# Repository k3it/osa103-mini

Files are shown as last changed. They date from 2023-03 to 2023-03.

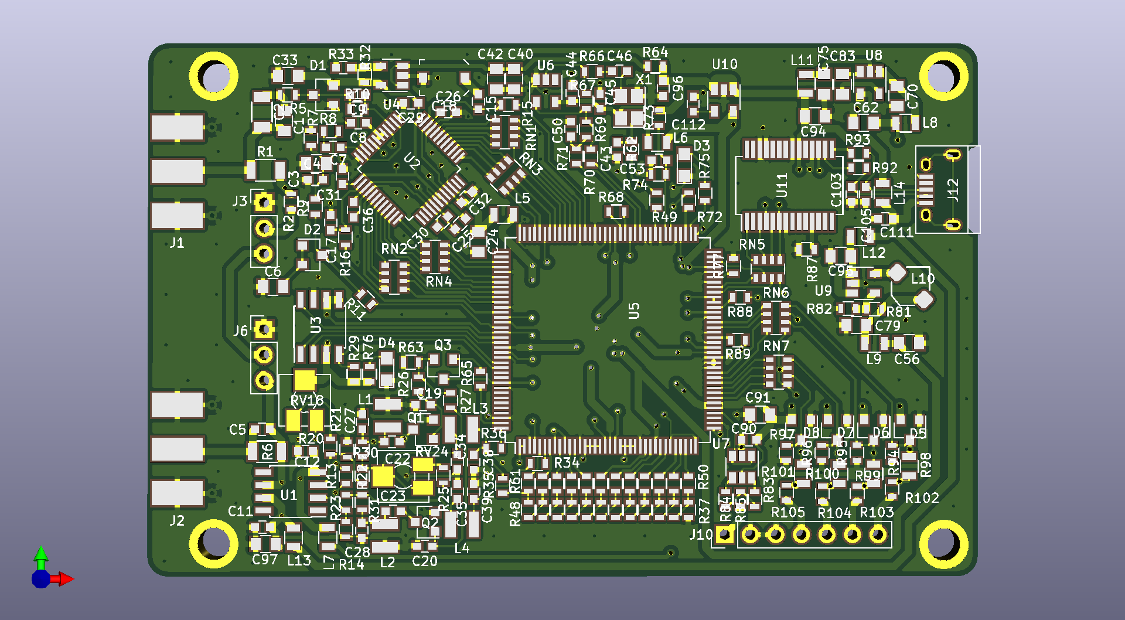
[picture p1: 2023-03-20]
osa103-mini/osa103k-pcb-front.png

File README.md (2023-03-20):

# osa103-mini
Software Defined Multifunctional Measurment Device - VNA, Oscilloscope, Antenna Analyzer, Signal Generator, SDR trasceiver etc

- Some years ago, I entered the OSA103 schematic, published by the device's author, into KiCad, and routed and created the PCB. I was able to assemble the device and was in the process of debugging it. It was a personal project undertaken out of pure curiosity and to learn KiCad. Unfortunately, my vision started to deteriorate to the point where troubleshooting a small SMD board was no longer enjoyable, and I ultimately abandoned the project. I am releasing all of the files from the project directory, including the gerbers, in case someone finds them useful.

- All credit for the original device goes to the person named Sergey from Perm, Russia. You may be able to reach him via a forum on a site called cqham or https://www.osa103.ru (which seems to be down as of spring 2023).   I have no contacts with the forum since the start of the war in Feb 2022.  

- Please note that you may need to pay for a software license to use the official software for this board. I haven't kept up with the development, so use this project at your own risk. That being said, this is an ingenious and clever device, so have fun!

- I have no affiliation or contact with the author or the websites mentioned above, and I have no idea about the author's position regarding the ongoing invasion of Ukraine. However, I hope that the author stands against it, which seems to be the case with the majority of intelligent people. When you communicate with Sergey may be  you will be able clarify his stance.  Thank you




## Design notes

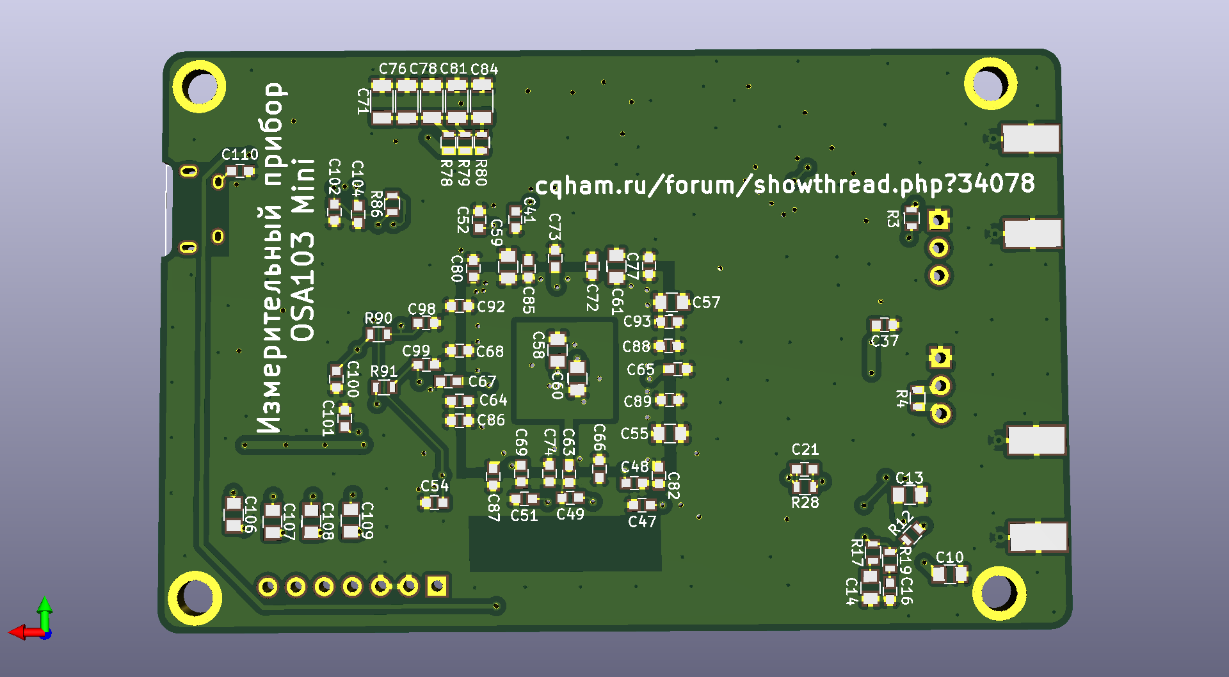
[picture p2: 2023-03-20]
osa103-mini/osa103k-pcb-back.png

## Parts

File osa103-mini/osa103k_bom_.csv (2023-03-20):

Component | Description | Part | References | Value | Footprint | Quantity Per PCB | Datasheet
1 | Unpolarized capacitor | C | C11 C12 C25 C26 C29 C31 C36 C46 C47 C48 C49 C50 C51 C53 C102 | 0.1uF | C_0603 | 15
2 | Unpolarized capacitor | C | C112 R33 | 10nF | C_0603 | 2
3 | Unpolarized capacitor | C | C1 C6 C10 C13 C24 C33 C40 C42 C55 C56 C57 C58 C59 C60 C61 C62 C70 C75 C79 C83 C91 C94 C95 C97 | 10uF | C_0805 | 24
4 | Unpolarized capacitor | C | C3 C15 C34 C35 | 15p | C_0603 | 4
5 | Unpolarized capacitor | C | C7 C8 C19 C20 C21 C22 C23 C30 C32 C37 C41 C43 C44 C45 C52 C63 C64 C65 C66 C67 C68 C69 C72 C73 C74 C77 C80 C82 C85 C86 C87 C88 C89 C90 C92 C93 C96 C98 C99 C100 C101 C104 C110 C111 | 1uF | C_0603 | 44
6 | Unpolarized capacitor | C | C5 C38 C39 | 2.2p | C_0603 | 3
7 | Unpolarized capacitor | C | C2 C71 C76 C78 C81 C84 | 22uF | C_1206 | 6
8 | Variable capacitor | C_Variable | C18 | 3..10p | C_Trimmer_Murata_TZC3 | 1
9 | Unpolarized capacitor | C | C106 C107 C108 C109 | 3.6p | C_0805 | 4
10 | Unpolarized capacitor | C | C4 C14 | 470p | C_0805 | 2
11 | Unpolarized capacitor | C | C103 C105 | 47p | C_0603 | 2
12 | Unpolarized capacitor | C | C27 C28 | 6.2p | C_0603 | 2
13 | Unpolarized capacitor | C | C9 C16 C17 C54 | NI | C_0603 | 4
14 | BAV99 High-speed switching diodes | BAV99 | D1 D2 D5 D6 D7 D8 | BAV99 | SOT-23 | 6 | www.nxp.com/documents/data_sheet/BAV99_SER.pdf
15 | LED generic | LED | D4 | green | LED_0805 | 1
16 | LED generic | LED | D3 | red | LED_0805 | 1
17 | Generic connector, single row, 01x03 | Conn_01x03 | J3 J6 | Conn_01x03 | Pin_Header_Straight_1x03_Pitch2.54mm | 2
18 | Generic connector, single row, 01x07 | Conn_01x07 | J10 | Conn_01x07 | Pin_Header_Straight_1x07_Pitch2.54mm | 1
19 | coaxial connector (BNC, SMA, SMB, SMC, Cinch/RCA, ...) | Conn_Coaxial | J1 J2 | Conn_Coaxial | Molex_SMA_Jack_Edge_Mount | 2
20 | USB mini/micro connector | USB_OTG | J12 | USB_OTG | USB_Micro-B | 1
21 | Inductor | L | L10 | 10uH | CDRH3D16 | 1
22 | Inductor | L | L1 L2 L3 L4 | 560n | Neosid_Inductor_SM-NE29_SMD1008 | 4
23 | Ferrite bead, small symbol | Ferrite_Bead_Small | L6 L7 L8 L11 L13 L14 | BLM21AG102 | R_0805 | 6
24 | Ferrite bead, small symbol | Ferrite_Bead_Small | L5 L9 L12 | BLM21PG221 | R_0805 | 3
25 | 45V Vce, 0.8A Ic, NPN, SOT-23 | BC817 | Q1 Q2 Q3 | BC846 | SOT-23 | 3 | http://www.fairchildsemi.com/ds/BC/BC817.pdf
26 | Resistor | R | R2 R3 R35 R78 R79 R80 | 1 | R_0603 | 6
27 | Resistor | R | R5 R10 R85 | 10 | R_0603 | 3
28 | Resistor | R | R49 R62 R69 R72 R90 R91 | 10k | R_0603 | 6
29 | Resistor | R | R64 R92 R93 | 15 | R_0603 | 3
30 | Resistor | R | R22 R23 | 200 | R_0603 | 2
31 | Resistor | R | R13 R17 R20 | 20k | R_0603 | 3
32 | Resistor | R | R36 R73 R74 R94 R95 R96 R97 | 24.9k 1% | R_0603 | 7
33 | Resistor | R | R26 R30 R31 R34 R38 R39 R40 R41 R42 R43 R44 R45 R46 R47 R48 R65 | 240 1% | R_0603 | 16
34 | Resistor | R | R11 R21 | 270 | R_0603 | 2
35 | Resistor | R | R28 R67 | 2M | R_0603 | 2
36 | Resistor | R | R4 R88 R89 | 2k 1% | R_0603 | 3
37 | Resistor | R | R14 | 390 | R_0603 | 1
38 | Resistor | R | R25 R37 R50 R51 R52 R53 R54 R55 R56 R57 R58 R59 R60 R61 R102 R103 R104 R105 | 470 1% | R_0603 | 18
39 | Resistor | R | R1 R6 | 49.9 1% | R_1206 | 2
40 | Resistor | R | R29 R75 R76 R82 | 5.1k | R_0603 | 4
41 | Resistor | R | R66 R70 R77 R83 R84 R87 | 68 | R_0603 | 6
42 | Resistor | R | R81 | 7.5k | R_0603 | 1
43 | Resistor | R | R98 R99 R100 R101 | 75k 1% | R_0805 | 4
44 | Resistor | R | R32 | 8.2k | R_0603 | 1
45 | Resistor | R | R7 R8 R15 R16 R71 | 82 | R_0603 | 5
46 | Resistor | R | R9 R12 R27 R63 R86 | 910 | R_0603 | 5
47 | Resistor | R | R19 R68 | NI | R_0603 | 2
48 | 4 Resistor network, parallel topology, DIP package | R_Pack04 | RN1 RN2 RN3 RN4 RN5 RN6 RN7 | 150 | R_Array_Convex_4x0603 | 7
49 | Potentiometer | POT | RV24 | 1k | Potentiometer_Trimmer_Vishay_TS53YJ | 1
50 | Potentiometer | POT | RV18 | 20k | Potentiometer_Trimmer_Vishay_TS53YJ | 1
51 | Single NOT Gate, Low-Voltage CMOS | 74LVC1G04 | U6 | 74LVC1GU04 | SOT-23-5 | 1 | http://www.ti.com/lit/sg/scyt129e/scyt129e.pdf
52 | Dual NOT Gate Schmidt Triggered, Low-Voltage CMOS | 74LVC2G14 | U7 | 74LVC2G14 | SOT-23-6 | 1 | http://www.ti.com/lit/sg/scyt129e/scyt129e.pdf
53 |  | AD8009ARZ | U1 | AD8009ARZ | SOIC-8_3.9x4.9mm_Pitch1.27mm | 1
54 |  | AD9288BST-100 | U2 | AD9288BST-40 | LQFP-48_7x7mm_Pitch0.5mm | 1
55 |  | AT45DB041D-SU | U3 | AT45DB041D-SU | SOIC-8_3.9x4.9mm_Pitch1.27mm | 1
56 | USB to Serial Interface, SSOP-28 | FT232RL | U11 | FT232RL | SSOP-28_5.3x10.2mm_Pitch0.65mm | 1 | http://www.ftdichip.com/Products/ICs/FT232RL.htm
57 | 300mA low dropout linear regulator, low quiescent current very, low noise, shutdown pin, 0.8V fixed positive output, SOT-23-5/SOT-353-5/SC-70-5 | LDK130-08_SOT23_SOT353 | U10 | LDK130-08_SOT23_SOT353 | SOT-23-5 | 1 | http://www.st.com/content/ccc/resource/technical/document/datasheet/29/10/f7/87/2f/66/47/f4/DM00076097.pdf/files/DM00076097.pdf/jcr:content/translations/en.DM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
58 | 150mA 16V Low-noise Low-dropout Regulator With Shutdown, 1.8V output voltage, SOT-23-5 | LP2985-1.8 | U4 | LP2985-1.8 | SOT-23-5 | 1 | http://www.ti.com/lit/ds/symlink/lp2985.pdf
59 |  | TPS60403_DBV_5 | U8 | TPS60403_DBV_5 | SOT-23-5 | 1
60 | SOT-23-5, High-Efficiency Step-Down DC-DC Converter, Adjustable | TPS62200DBV | U9 | TPS62200DBV | SOT-23-5 | 1 | http://www.ti.com/lit/ds/symlink/tps62201.pdf
61 |  | XC6SLXN-TQG144 | U5 | XC6SLXN-TQG144 | TQFP-144_20x20mm_Pitch0.5mm | 1
62 | Voltage-Controlled Crystal Clock Oscillator, DIP14-style metal package | VTCXO-14 | X1 | VTCXO-14 | Crystal_SMD_SeikoEpson_TSX3225-4pin_3.2x2.5mm | 1 | http://www.golledge.com/pdf/products/tcxos/gtxos14.pdf
Component Groups: | 62
Component Count: | 267
Fitted Components: | 267
Number of PCBs: | 1
Total components: | 267
Schematic Version:
Schematic Date:
BoM Date: | 31/01/2018 22:51:36
Schematic Source: | C:\Users\uncle_ziba\Documents\Dropbox\kicad\osa103-kl\osa103k\osa103k.sch
KiCad Version: | Eeschema (2018-01-26 revision 0d532b43d)-makepkg

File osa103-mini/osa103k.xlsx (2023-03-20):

Proj: | None |  |  |  |  |  | Board Qty: | 1
Co.: | None |  |  |  |  |  | Total Cost: | $0.00 |  |  |  | $0.00 |  |  |  |  | $0.00
Prj date: | None |  |  |  |  |  | Unit Cost: | $0.00 |  |  |  | 0 of 62 parts found |  |  |  |  | 0 of 62 parts found
$ date: | 2018-01-31 22:53:21
Global Part Info |  |  |  |  |  |  |  |  | Digi-Key |  |  |  |  | Mouser
Refs | Value | Desc | Footprint | Manf | Manf# | Qty | Unit$ | Ext$ | Avail | Purch | Unit$ | Ext$ | Cat# | Avail | Purch | Unit$ | Ext$ | Cat#
C1,C6,C10,C13,C24,C33,C40,C42,C55-C62,C70,C75,C79,C83,C91,C94,C95,C97 | 10uF |  | Capacitors_SMD:C_0805 |  |  | 24 | $0.00 | $0.00
C103,C105 | 47p |  | Capacitors_SMD:C_0603 |  |  | 2 | $0.00 | $0.00
C106-C109 | 3.6p |  | Capacitors_SMD:C_0805 |  |  | 4 | $0.00 | $0.00
C11,C12,C25,C26,C29,C31,C36,C46-C51,C53,C102 | 0.1uF |  | Capacitors_SMD:C_0603 |  |  | 15 | $0.00 | $0.00
C18 | 3..10p |  | Capacitors_SMD:C_Trimmer_Murata_TZC3 |  |  | 1 | $0.00 | $0.00
C2,C71,C76,C78,C81,C84 | 22uF |  | Capacitors_SMD:C_1206 |  |  | 6 | $0.00 | $0.00
C27,C28 | 6.2p |  | Capacitors_SMD:C_0603 |  |  | 2 | $0.00 | $0.00
C3,C15,C34,C35 | 15p |  | Capacitors_SMD:C_0603 |  |  | 4 | $0.00 | $0.00
C4,C14 | 470p |  | Capacitors_SMD:C_0805 |  |  | 2 | $0.00 | $0.00
C5,C38,C39 | 2.2p |  | Capacitors_SMD:C_0603 |  |  | 3 | $0.00 | $0.00
C7,C8,C19-C23,C30,C32,C37,C41,C43-C45,C52,C63-C69,C72-C74,C77,C80,C82,C85-C90,C92,C93,C96,C98-C101,C104,C110,C111 | 1uF |  | Capacitors_SMD:C_0603 |  |  | 44 | $0.00 | $0.00
C9,C16,C17,C54 | NI |  | Capacitors_SMD:C_0603 |  |  | 4 | $0.00 | $0.00
D1,D2,D5-D8 | BAV99 |  | TO_SOT_Packages_SMD:SOT-23 |  |  | 6 | $0.00 | $0.00
D3 | red |  | LEDs:LED_0805 |  |  | 1 | $0.00 | $0.00
D4 | green |  | LEDs:LED_0805 |  |  | 1 | $0.00 | $0.00
J1,J2 | Conn_Coaxial |  | Connectors_Molex:Molex_SMA_Jack_Edge_Mount |  |  | 2 | $0.00 | $0.00
J10 | Conn_01x07 |  | Pin_Headers:Pin_Header_Straight_1x07_Pitch2.54mm |  |  | 1 | $0.00 | $0.00
J12 | USB_OTG |  | Connect:USB_Micro-B |  |  | 1 | $0.00 | $0.00
J3,J6 | Conn_01x03 |  | Pin_Headers:Pin_Header_Straight_1x03_Pitch2.54mm |  |  | 2 | $0.00 | $0.00
L1-L4 | 560n |  | Inductors_NEOSID:Neosid_Inductor_SM-NE29_SMD1008 |  |  | 4 | $0.00 | $0.00
L10 | 10uH |  | son:CDRH3D16 |  |  | 1 | $0.00 | $0.00
L5,L9,L12 | BLM21PG221 |  | Resistors_SMD:R_0805 |  |  | 3 | $0.00 | $0.00
L6-L8,L11,L13,L14 | BLM21AG102 |  | Resistors_SMD:R_0805 |  |  | 6 | $0.00 | $0.00
Q1-Q3 | BC846 |  | TO_SOT_Packages_SMD:SOT-23 |  |  | 3 | $0.00 | $0.00
R1,R6 | 49.9 1% |  | Resistors_SMD:R_1206 |  |  | 2 | $0.00 | $0.00
R11,R21 | 270 |  | Resistors_SMD:R_0603 |  |  | 2 | $0.00 | $0.00
R13,R17,R20 | 20k |  | Resistors_SMD:R_0603 |  |  | 3 | $0.00 | $0.00
R14 | 390 |  | Resistors_SMD:R_0603 |  |  | 1 | $0.00 | $0.00
R19,R68 | NI |  | Resistors_SMD:R_0603 |  |  | 2 | $0.00 | $0.00
R2,R3,R35,R78-R80 | 1 |  | Resistors_SMD:R_0603 |  |  | 6 | $0.00 | $0.00
R22,R23 | 200 |  | Resistors_SMD:R_0603 |  |  | 2 | $0.00 | $0.00
R25,R37,R50-R61,R102-R105 | 470 1% |  | Resistors_SMD:R_0603 |  |  | 18 | $0.00 | $0.00
R26,R30,R31,R34,R38-R48,R65 | 240 1% |  | Resistors_SMD:R_0603 |  |  | 16 | $0.00 | $0.00
R28,R67 | 2M |  | Resistors_SMD:R_0603 |  |  | 2 | $0.00 | $0.00
R29,R75,R76,R82 | 5.1k |  | Resistors_SMD:R_0603 |  |  | 4 | $0.00 | $0.00
R32 | 8.2k |  | Resistors_SMD:R_0603 |  |  | 1 | $0.00 | $0.00
R33,C112 | 10nF |  | Capacitors_SMD:C_0603 |  |  | 2 | $0.00 | $0.00
R36,R73,R74,R94-R97 | 24.9k 1% |  | Resistors_SMD:R_0603 |  |  | 7 | $0.00 | $0.00
R4,R88,R89 | 2k 1% |  | Resistors_SMD:R_0603 |  |  | 3 | $0.00 | $0.00
R49,R62,R69,R72,R90,R91 | 10k |  | Resistors_SMD:R_0603 |  |  | 6 | $0.00 | $0.00
R5,R10,R85 | 10 |  | Resistors_SMD:R_0603 |  |  | 3 | $0.00 | $0.00
R64,R92,R93 | 15 |  | Resistors_SMD:R_0603 |  |  | 3 | $0.00 | $0.00
R66,R70,R77,R83,R84,R87 | 68 |  | Resistors_SMD:R_0603 |  |  | 6 | $0.00 | $0.00
R7,R8,R15,R16,R71 | 82 |  | Resistors_SMD:R_0603 |  |  | 5 | $0.00 | $0.00
R81 | 7.5k |  | Resistors_SMD:R_0603 |  |  | 1 | $0.00 | $0.00
R9,R12,R27,R63,R86 | 910 |  | Resistors_SMD:R_0603 |  |  | 5 | $0.00 | $0.00
R98-R101 | 75k 1% |  | Resistors_SMD:R_0805 |  |  | 4 | $0.00 | $0.00
RN1-RN7 | 150 |  | Resistors_SMD:R_Array_Convex_4x0603 |  |  | 7 | $0.00 | $0.00
RV18 | 20k |  | Potentiometers:Potentiometer_Trimmer_Vishay_TS53YJ |  |  | 1 | $0.00 | $0.00
RV24 | 1k |  | Potentiometers:Potentiometer_Trimmer_Vishay_TS53YJ |  |  | 1 | $0.00 | $0.00
U1 | AD8009ARZ |  | Housings_SOIC:SOIC-8_3.9x4.9mm_Pitch1.27mm |  |  | 1 | $0.00 | $0.00
U10 | LDK130-08_SOT23_SOT353 |  | TO_SOT_Packages_SMD:SOT-23-5 |  |  | 1 | $0.00 | $0.00
U11 | FT232RL |  | Housings_SSOP:SSOP-28_5.3x10.2mm_Pitch0.65mm |  |  | 1 | $0.00 | $0.00
U2 | AD9288BST-40 |  | Housings_QFP:LQFP-48_7x7mm_Pitch0.5mm |  |  | 1 | $0.00 | $0.00
U3 | AT45DB041D-SU |  | Housings_SOIC:SOIC-8_3.9x4.9mm_Pitch1.27mm |  |  | 1 | $0.00 | $0.00
U4 | LP2985-1.8 |  | TO_SOT_Packages_SMD:SOT-23-5 |  |  | 1 | $0.00 | $0.00
U5 | XC6SLXN-TQG144 |  | Housings_QFP:TQFP-144_20x20mm_Pitch0.5mm |  |  | 1 | $0.00 | $0.00
U6 | 74LVC1GU04 |  | TO_SOT_Packages_SMD:SOT-23-5 |  |  | 1 | $0.00 | $0.00
U7 | 74LVC2G14 |  | TO_SOT_Packages_SMD:SOT-23-6 |  |  | 1 | $0.00 | $0.00
U8 | TPS60403_DBV_5 |  | TO_SOT_Packages_SMD:SOT-23-5 |  |  | 1 | $0.00 | $0.00
U9 | TPS62200DBV |  | TO_SOT_Packages_SMD:SOT-23-5 |  |  | 1 | $0.00 | $0.00
X1 | VTCXO-14 |  | Crystals:Crystal_SMD_SeikoEpson_TSX3225-4pin_3.2x2.5mm |  |  | 1 | $0.00 | $0.00

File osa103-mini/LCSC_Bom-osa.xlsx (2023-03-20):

Note: precise search for LCSC part number.
Quantity | Manufacture Part Number | Manufacturer(optional) | Description(optional) | LCSC Part Number(optional) | Package(optional)
10 | BAV99LT1G
1 | APT2012SGC
1 | AP2012EC
2 | 73251-1150
1 | CDRH3D16/HPNP-100MC
4 | NLV25T-R56J-PF
1 | 10118193-0001LF
10 | BLM21AG102SZ1D
3 | BLM21AG221SZ1D
3 | BC846ALT1G
10 | EXB-V8V151JV
1 | TS53YJ102MR10
1 | TS53YJ203MR10
1 | SN74LVC1G04DBVR
1 | SN74LVC2G14DBVR
1 | AD8009ARZ
1 | AD9288BSTZ-40
1 | AT45DB041E-SSHN2B-T
1 | FT232RL-REEL
1 | LDK130M33R
1 | LP2985AIM5-3.3/NOPB
1 | TPS60403DBVR
1 | TPS62200DBVR
1 | XC6SLX9-2TQG144C
1 | TZC3R100A110R00
17 | GRT033R60J104KE01D
24 | LMK212ABJ106MG-T
4 | VJ0603A150JXACW1BC
50 | 885012106010
10 | C1206C226Z9VACTU
4 | 08051A3R6CAT2A
6 | MCT06030C5101FP500
1 | RR0816P-1822-D-26C
10 | C1608X5R0J106M080AB
1 | 885012206059
1 | 885012206042
1 | RR0816P-131-D
1 | SN74LVC1G04QDBVRQ1
1 | LMK107BBJ226MA-T
1 | CR0603-JW-106ELF
1 | OPA653IDBVT

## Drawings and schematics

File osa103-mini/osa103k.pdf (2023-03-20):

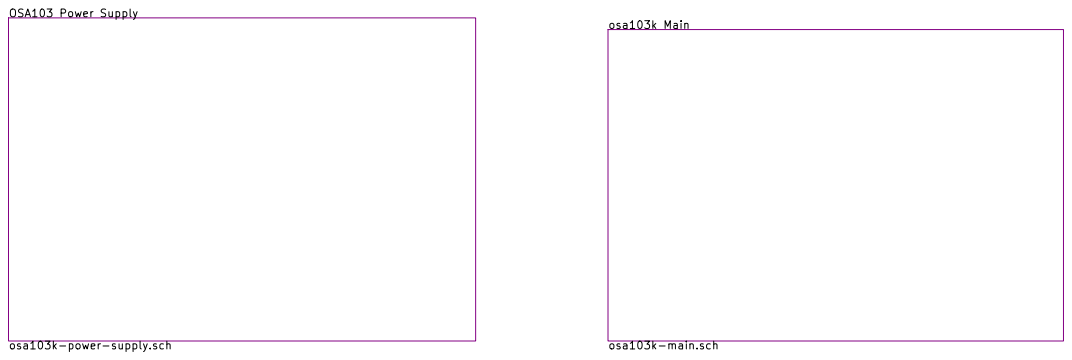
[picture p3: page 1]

Id: 1/3 Title: File: osa103k.sch Sheet: /

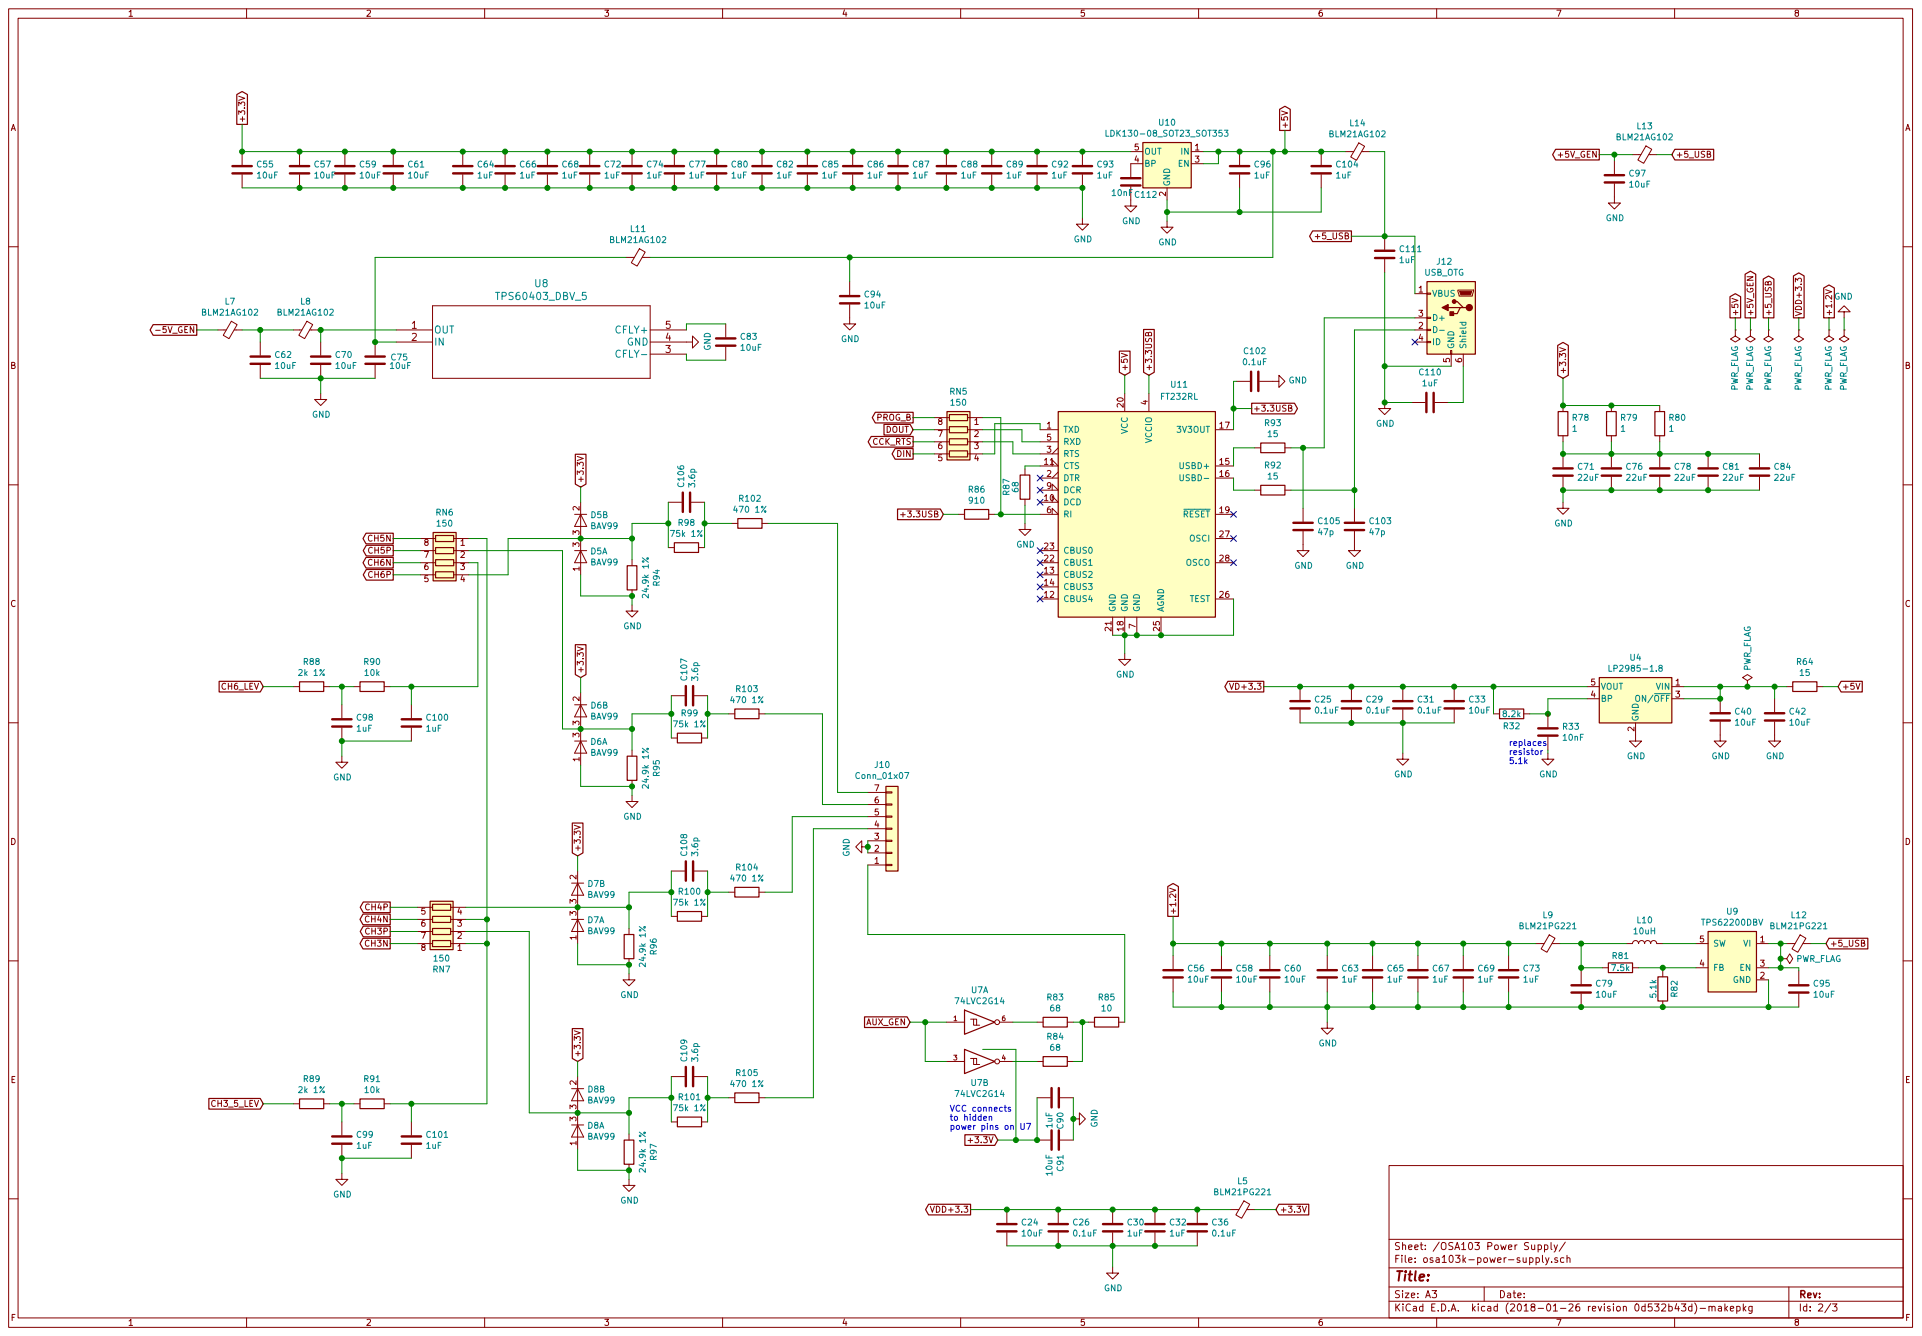
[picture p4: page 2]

7 DCR 9 DCD 10 VCC 20 CTS 11 GND 21 CBUS4 12 CBUS1 22 CBUS2 13 CBUS0 23 CBUS3 14 USBD+ 15 AGND 25 USBD- 16 TEST 26

Sheet: /OSA103 Power Supply/
File: osa103k-power-supply.sch
Id: 2/3 Title:

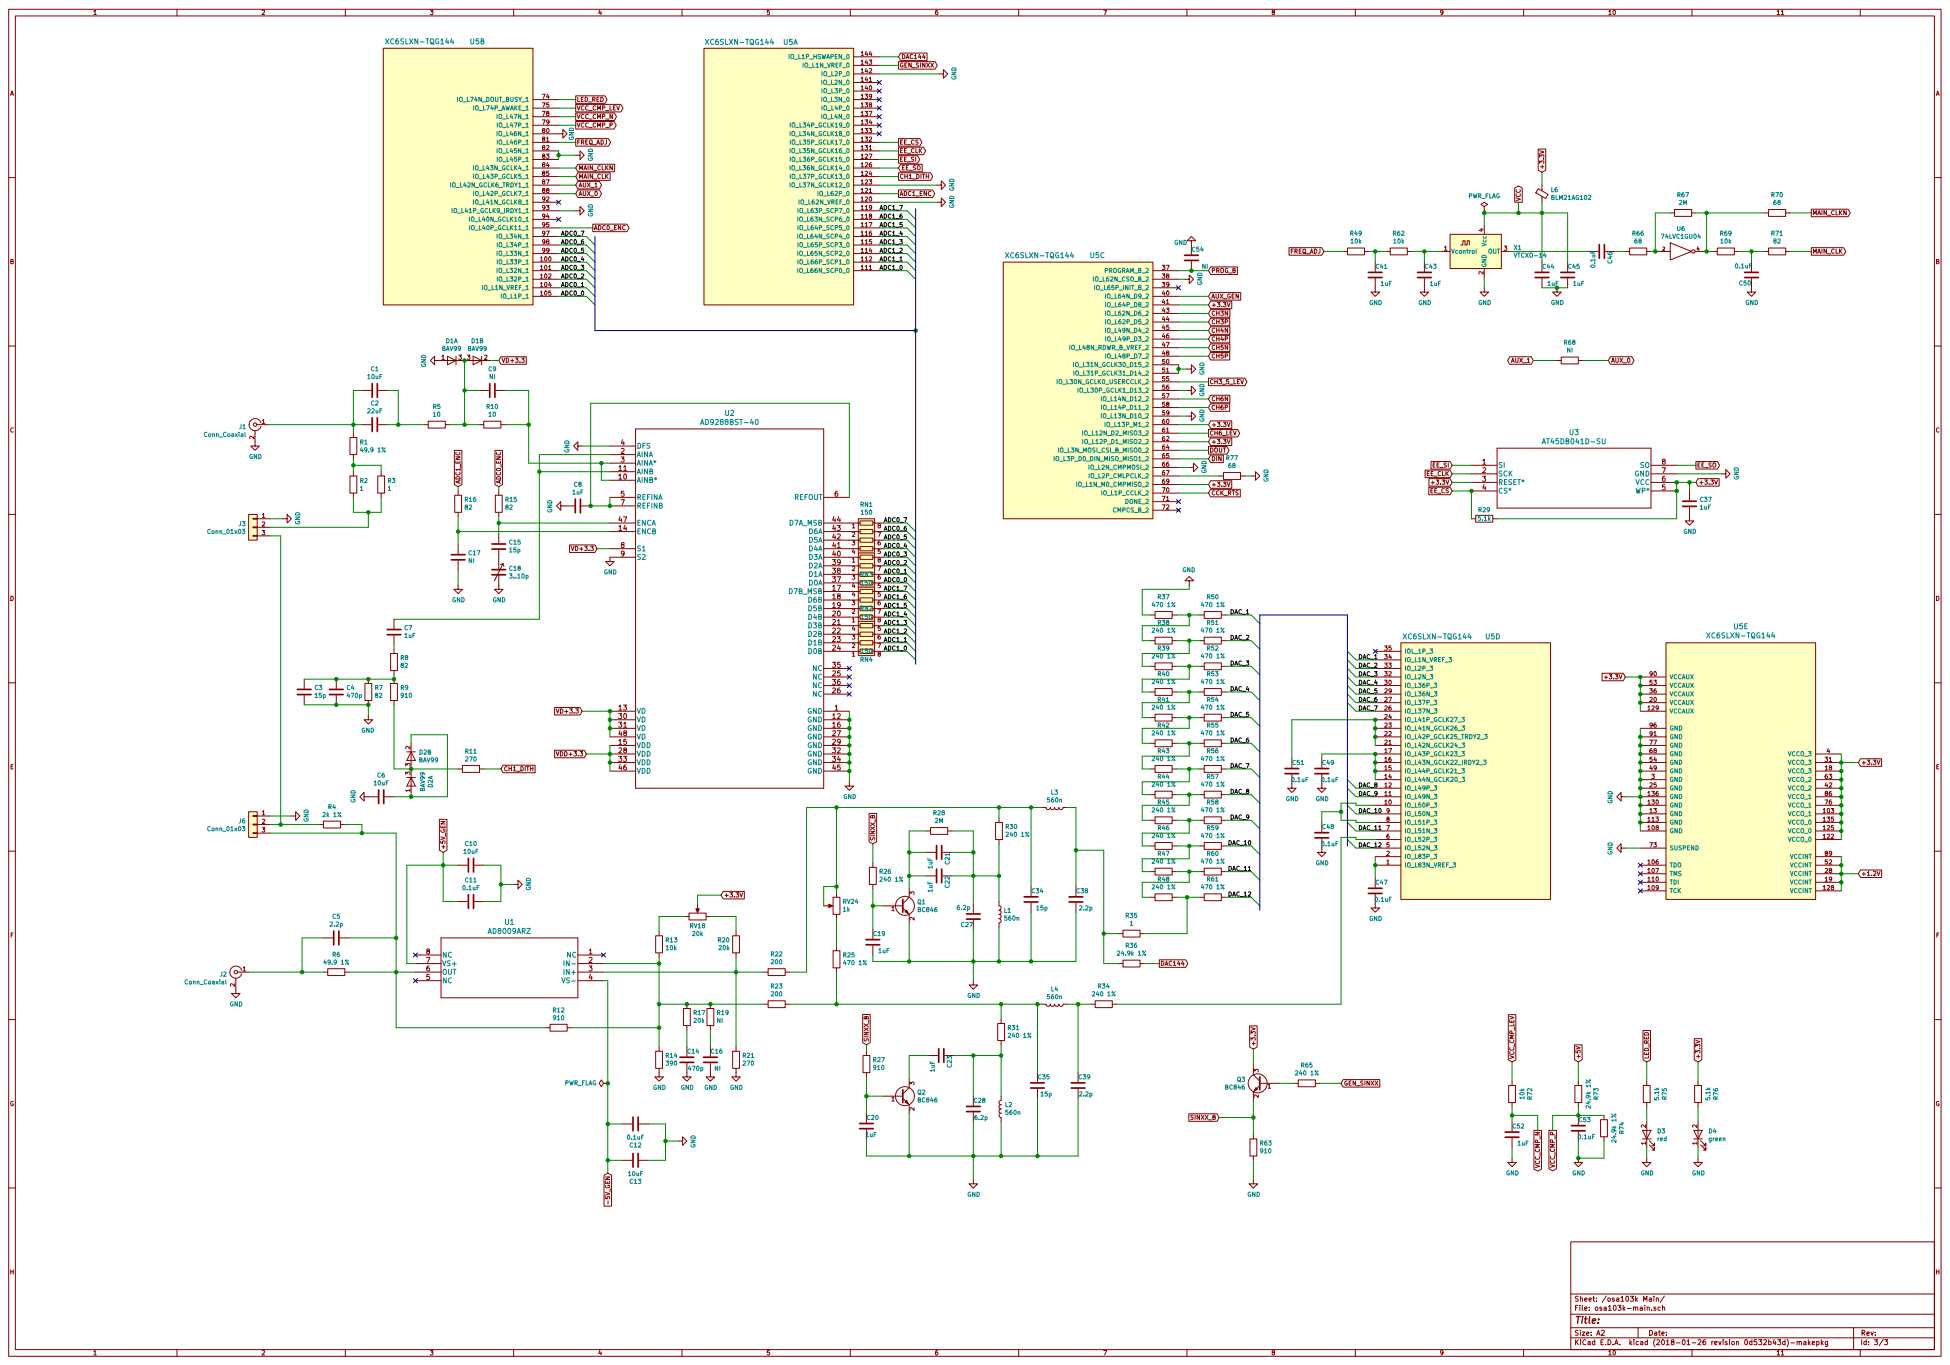
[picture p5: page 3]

2 | 8 RN2 7

Id: 3/3 Title: File: osa103k-main.sch Sheet: /osa103k Main/

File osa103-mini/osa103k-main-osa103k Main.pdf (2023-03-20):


2 | 8 RN2 7

Id: 3/3 Title: File: osa103k-main.sch Sheet: /osa103k Main/

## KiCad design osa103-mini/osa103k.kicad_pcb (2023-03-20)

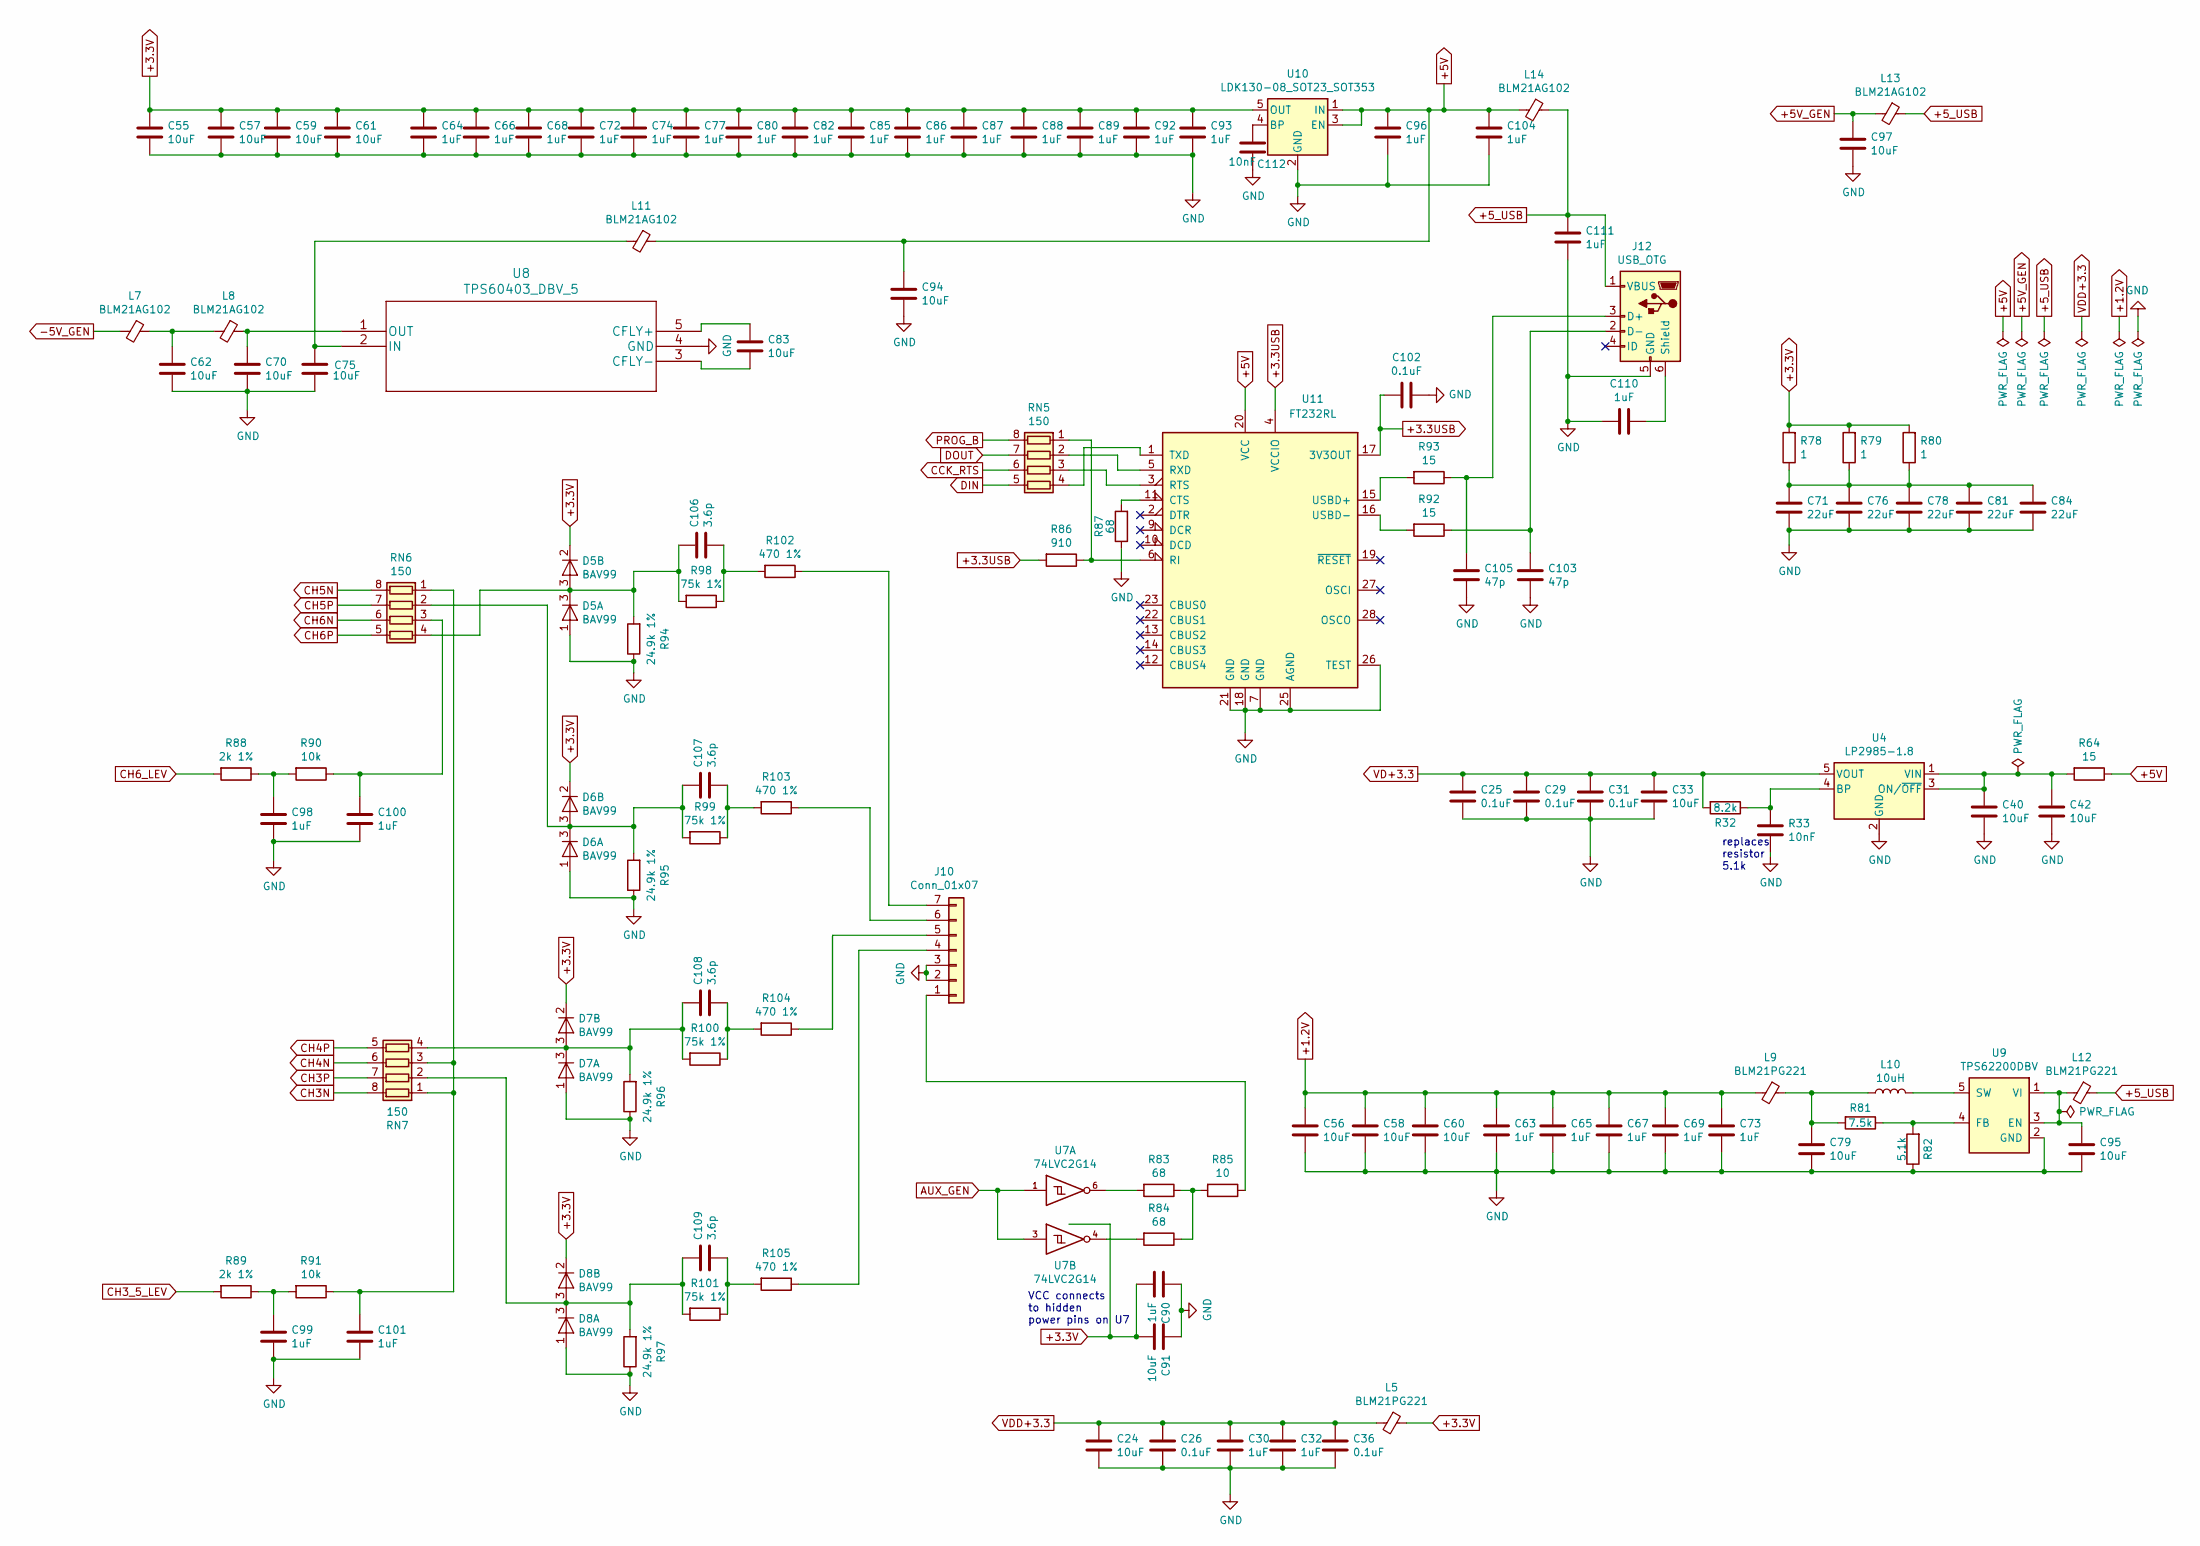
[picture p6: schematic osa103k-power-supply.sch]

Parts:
C24, C33, C40, C42, C55, C56, C57, C58, C59, C60, C61, C62, C70, C75, C79, C83, C91, C94, C95, C97: 10uF; C_0805
C25, C26, C29, C31, C36, C102: 0.1uF; C_0603
C30, C32, C63, C64, C65, C66, C67, C68, C69, C72, C73, C74, C77, C80, C82, C85, C86, C87, C88, C89, C90, C92, C93, C96, C98, C99, C100, C101, C104, C110, C111: 1uF; C_0603
C71, C76, C78, C81, C84: 22uF; C_1206
C103, C105: 47p; C_0603
C106, C107, C108, C109: 3.6p; C_0805
C112: 10nF; C_0603
D5, D6, D7, D8: BAV99; SOT-23
J10: Conn_01x07; Pin_Header_Straight_1x07_Pitch2.54mm
J12: USB_OTG; USB_Micro-B
L5, L9, L12: BLM21PG221; R_0805
L7, L8, L11, L13, L14: BLM21AG102; R_0805
L10: 10uH; CDRH3D16
R32: 8.2k; R_0603
R33: 10nF; C_0603
R64, R92, R93: 15; R_0603
R78, R79, R80: 1; R_0603
R81: 7.5k; R_0603
R82: 5.1k; R_0603
R83, R84, R87: 68; R_0603
R85: 10; R_0603
R86: 910; R_0603
R88, R89: 2k 1%; R_0603
R90, R91: 10k; R_0603
R94, R95, R96, R97: 24.9k 1%; R_0603
R98, R99, R100, R101: 75k 1%; R_0805
R102, R103, R104, R105: 470 1%; R_0603
RN5, RN6, RN7: 150; R_Array_Convex_4x0603
U4: LP2985-1.8; SOT-23-5
U7: 74LVC2G14; SOT-23-6
U8: TPS60403_DBV_5; SOT-23-5
U9: TPS62200DBV; SOT-23-5
U10: LDK130-08_SOT23_SOT353; SOT-23-5
U11: FT232RL; SSOP-28_5.3x10.2mm_Pitch0.65mm

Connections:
+1.2V: C56.1, C58.1, C60.1, C63.1, C65.1, C67.1, C69.1, C73.1, L9.2; also elsewhere on the board
+3.3USB: C102.2, R86.2, U11.4 (VCCIO), U11.17 (3V3OUT)
+3.3V: C55.1, C57.1, C59.1, C61.1, C64.1, C66.1, C68.1, C72.1, C74.1, C77.1, C80.1, C82.1, C85.1, C86.1, C87.1, C88.1, C89.1, C90.2, C91.2, C92.1, C93.1, D5.2 (K), D6.2 (K), D7.2 (K), D8.2 (K), L5.1, R78.2, R79.2, R80.2, U7.5 (+3.3V), U10.5 (OUT); also elsewhere on the board
+5V: C94.1, C96.1, C104.1, L11.1, L14.2, R64.1, U10.1 (IN), U10.3 (EN), U11.20 (VCC); also elsewhere on the board
+5V_GEN: C97.1, L13.2; also elsewhere on the board
+5_USB: C111.1, J12.1 (VBUS), L12.1, L13.1, L14.1
-5V_GEN: L7.2; also elsewhere on the board
AUX_GEN: U7.1, U7.3; also elsewhere on the board
CCK_RTS: RN5.6 (R3.2); also elsewhere on the board
CH3N: RN7.8 (R1.2); also elsewhere on the board
CH3P: RN7.7 (R2.2); also elsewhere on the board
CH3_5_LEV: R89.2; also elsewhere on the board
CH4N: RN7.6 (R3.2); also elsewhere on the board
CH4P: RN7.5 (R4.2); also elsewhere on the board
CH5N: RN6.8 (R1.2); also elsewhere on the board
CH5P: RN6.7 (R2.2); also elsewhere on the board
CH6N: RN6.6 (R3.2); also elsewhere on the board
CH6P: RN6.5 (R4.2); also elsewhere on the board
CH6_LEV: R88.2; also elsewhere on the board
DIN: RN5.5 (R4.2); also elsewhere on the board
DOUT: RN5.7 (R2.2); also elsewhere on the board
GND: C24.2, C25.2, C26.2, C29.2, C30.2, C31.2, C32.2, C33.2, C36.2, C40.2, C42.2, C55.2, C56.2, C57.2, C58.2, C59.2, C60.2, C61.2, C62.2, C63.2, C64.2, C65.2, C66.2, C67.2, C68.2, C69.2, C70.2, C71.2, C72.2, C73.2, C74.2, C75.2, C76.2, C77.2, C78.2, C79.2, C80.2, C81.2, C82.2, C84.2, C85.2, C86.2, C87.2, C88.2, C89.2, C90.1, C91.1, C92.2, C93.2, C94.2, C95.2, C96.2, C97.2, C98.2, C99.2, C100.2, C101.2, C102.1, C103.2, C104.2, C105.2, C110.2, C111.2, C112.1, D5.1 (A), D6.1 (A), D7.1 (A), D8.1 (A), J10.2, J10.3, J12.5 (GND), R33.2, R82.1, R87.1, R94.1, R95.1, R96.1, R97.1, U4.2 (GND), U7.2 (GND), U8.4 (GND), U9.2 (GND), U10.2 (GND), U11.7 (GND), U11.18 (GND), U11.21 (GND), U11.25 (AGND), U11.26 (TEST); also elsewhere on the board
unnamed: C40.1, C42.1, R64.2, U4.1 (VIN), U4.3 (ON/~OFF~)
unnamed: C62.1, L7.1, L8.2
unnamed: C70.1, L8.1, U8.1 (OUT)
unnamed: C71.1, C76.1, C78.1, C81.1, C84.1, R78.1, R79.1, R80.1
unnamed: C75.1, L11.2, U8.2 (IN)
unnamed: C79.1, L9.1, L10.1, R81.2
unnamed: C83.1, U8.5 (CFLY+)
unnamed: C83.2, U8.3 (CFLY-)
unnamed: C95.1, L12.2, U9.1 (VI), U9.3 (EN)
unnamed: C98.1, R88.1, R90.2
unnamed: C99.1, R89.1, R91.2
unnamed: C100.1, R90.1, RN6.3 (R3.1)
unnamed: C101.1, R91.1, RN6.1 (R1.1), RN7.1 (R1.1), RN7.3 (R3.1)
unnamed: C103.1, J12.2 (D-), R92.1
unnamed: C105.1, J12.3 (D+), R93.1
unnamed: C106.1, D5.3 (K), R94.2, R98.2, RN6.4 (R4.1)
unnamed: C106.2, R98.1, R102.2
unnamed: C107.1, D6.3 (K), R95.2, R99.2, RN6.2 (R2.1)
unnamed: C107.2, R99.1, R103.2
unnamed: C108.1, D7.3 (K), R96.2, R100.2, RN7.4 (R4.1)
unnamed: C108.2, R100.1, R104.2
unnamed: C109.1, D8.3 (K), R97.2, R101.2, RN7.2 (R2.1)
unnamed: C109.2, R101.1, R105.2
unnamed: C110.1, J12.6 (Shield)
unnamed: C112.2, U10.4 (BP)
unnamed: J10.1, R85.1
unnamed: J10.4, R105.1
unnamed: J10.5, R104.1
unnamed: J10.6, R103.1
unnamed: J10.7, R102.1
unnamed: L10.2, U9.5 (SW)
unnamed: R32.1, R33.1, U4.4 (BP)
unnamed: R81.1, R82.2, U9.4 (FB)
unnamed: R83.1, R84.1, R85.2
unnamed: R83.2, U7.6
unnamed: R84.2, U7.4
unnamed: R86.1, RN5.1 (R1.1), U11.6 (RI)
unnamed: R87.2, U11.11 (CTS)
unnamed: R92.2, U11.16 (USBD-)
unnamed: R93.2, U11.15 (USBD+)
unnamed: RN5.2 (R2.1), U11.5 (RXD)
unnamed: RN5.3 (R3.1), U11.3 (RTS)
unnamed: RN5.4 (R4.1), U11.1 (TXD)
PROG_B: RN5.8 (R1.2); also elsewhere on the board
VD+3.3: C25.1, C29.1, C31.1, C33.1, R32.2, U4.5 (VOUT); also elsewhere on the board
VDD+3.3: C24.1, C26.1, C30.1, C32.1, C36.1, L5.2; also elsewhere on the board

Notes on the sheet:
replaces resistor 5.1k
VCC connects to hidden power pins on U7

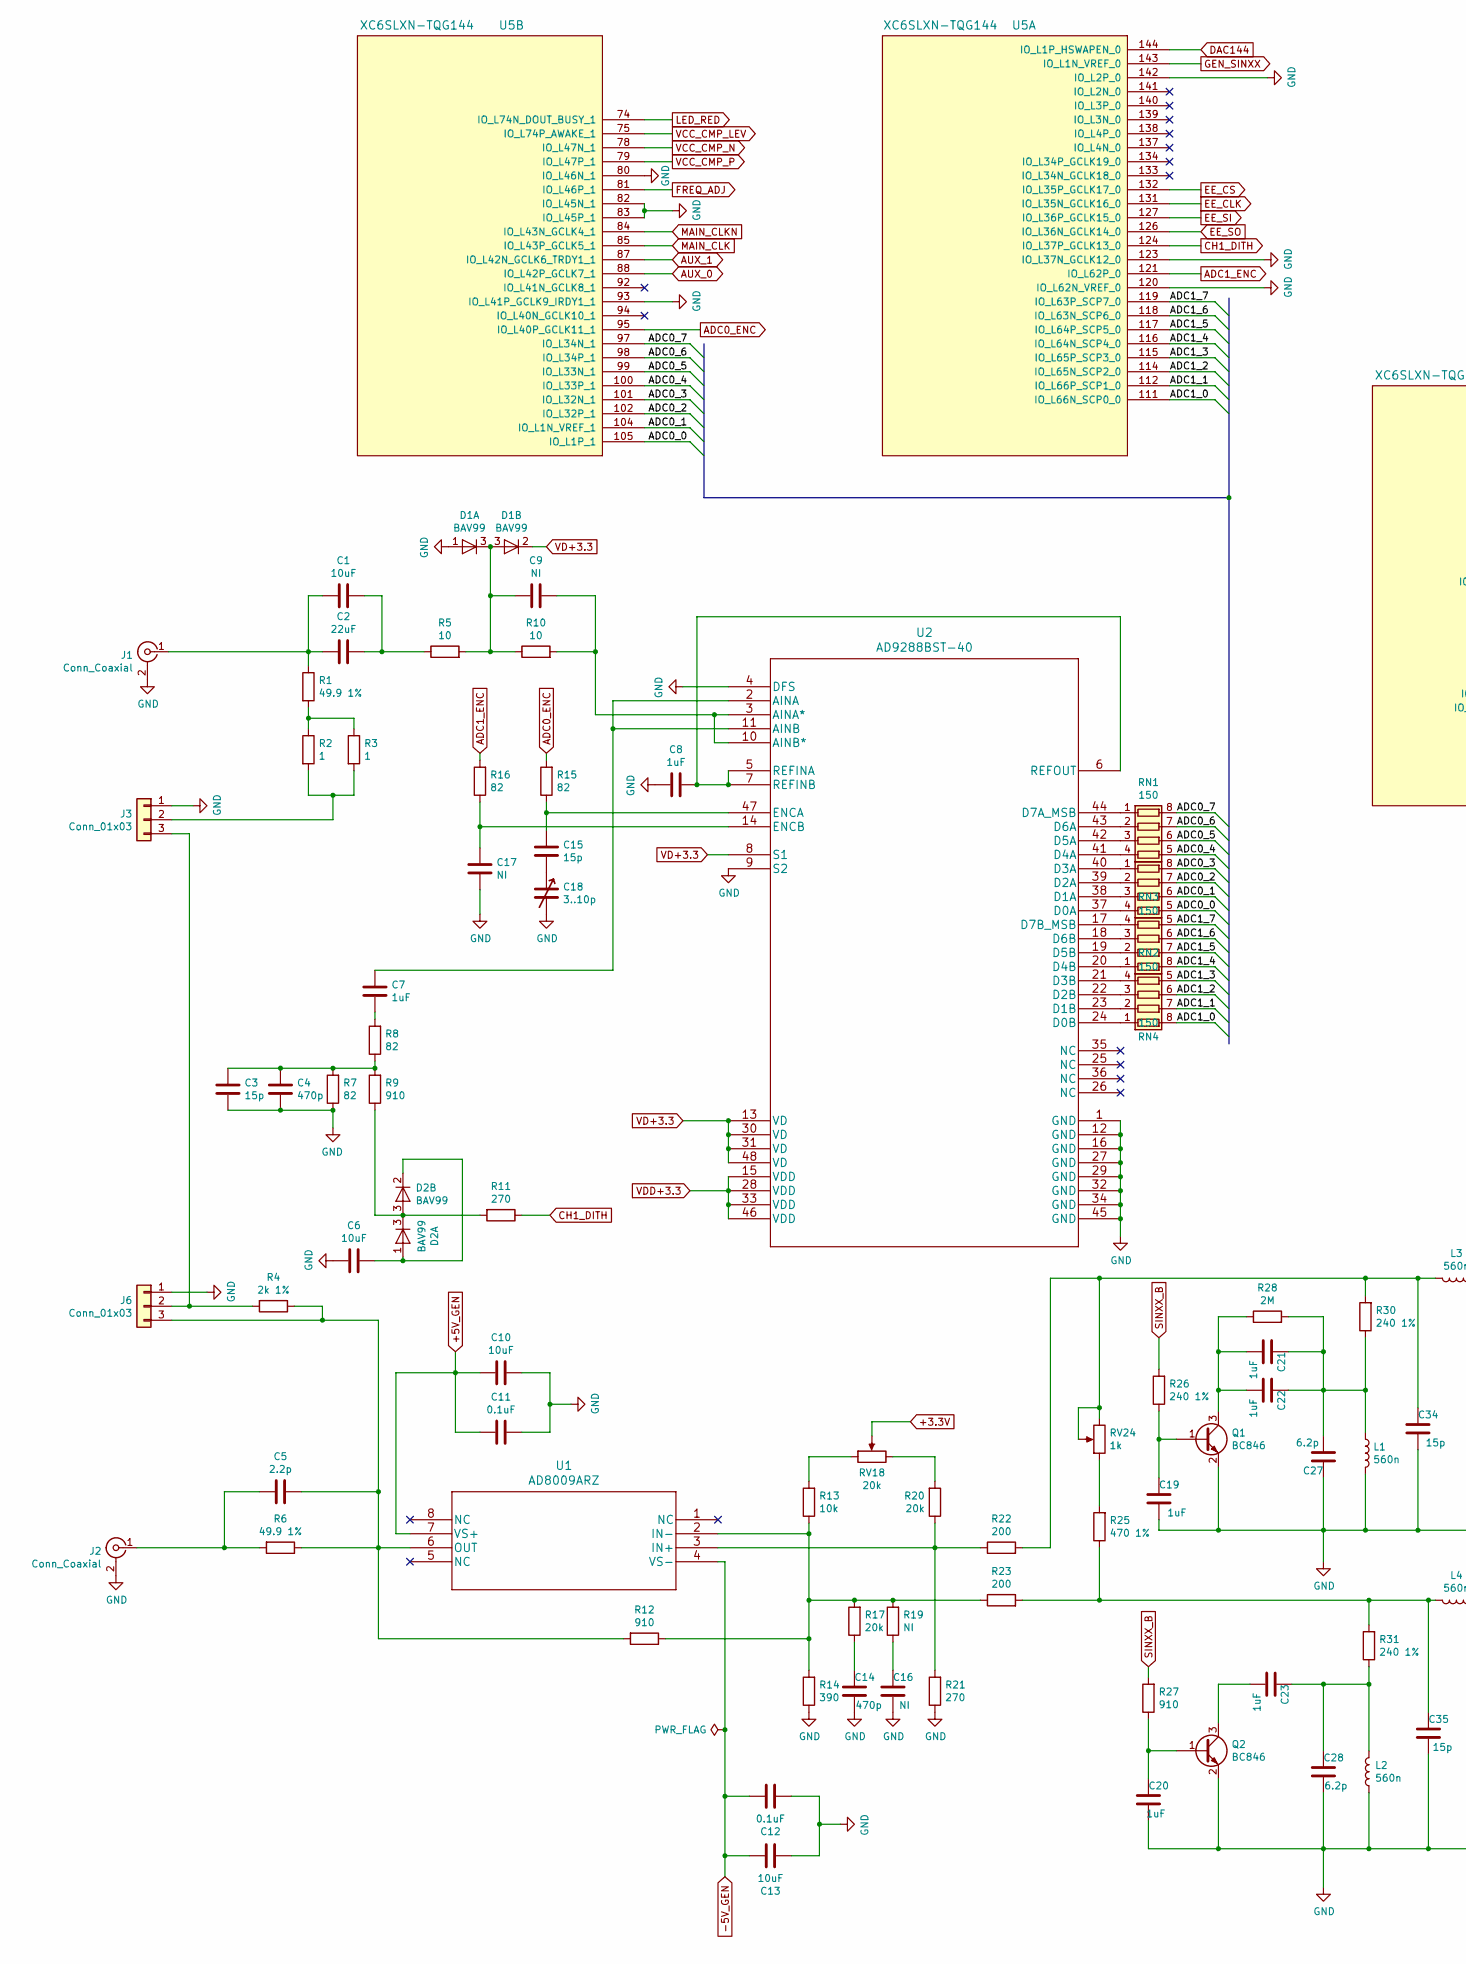
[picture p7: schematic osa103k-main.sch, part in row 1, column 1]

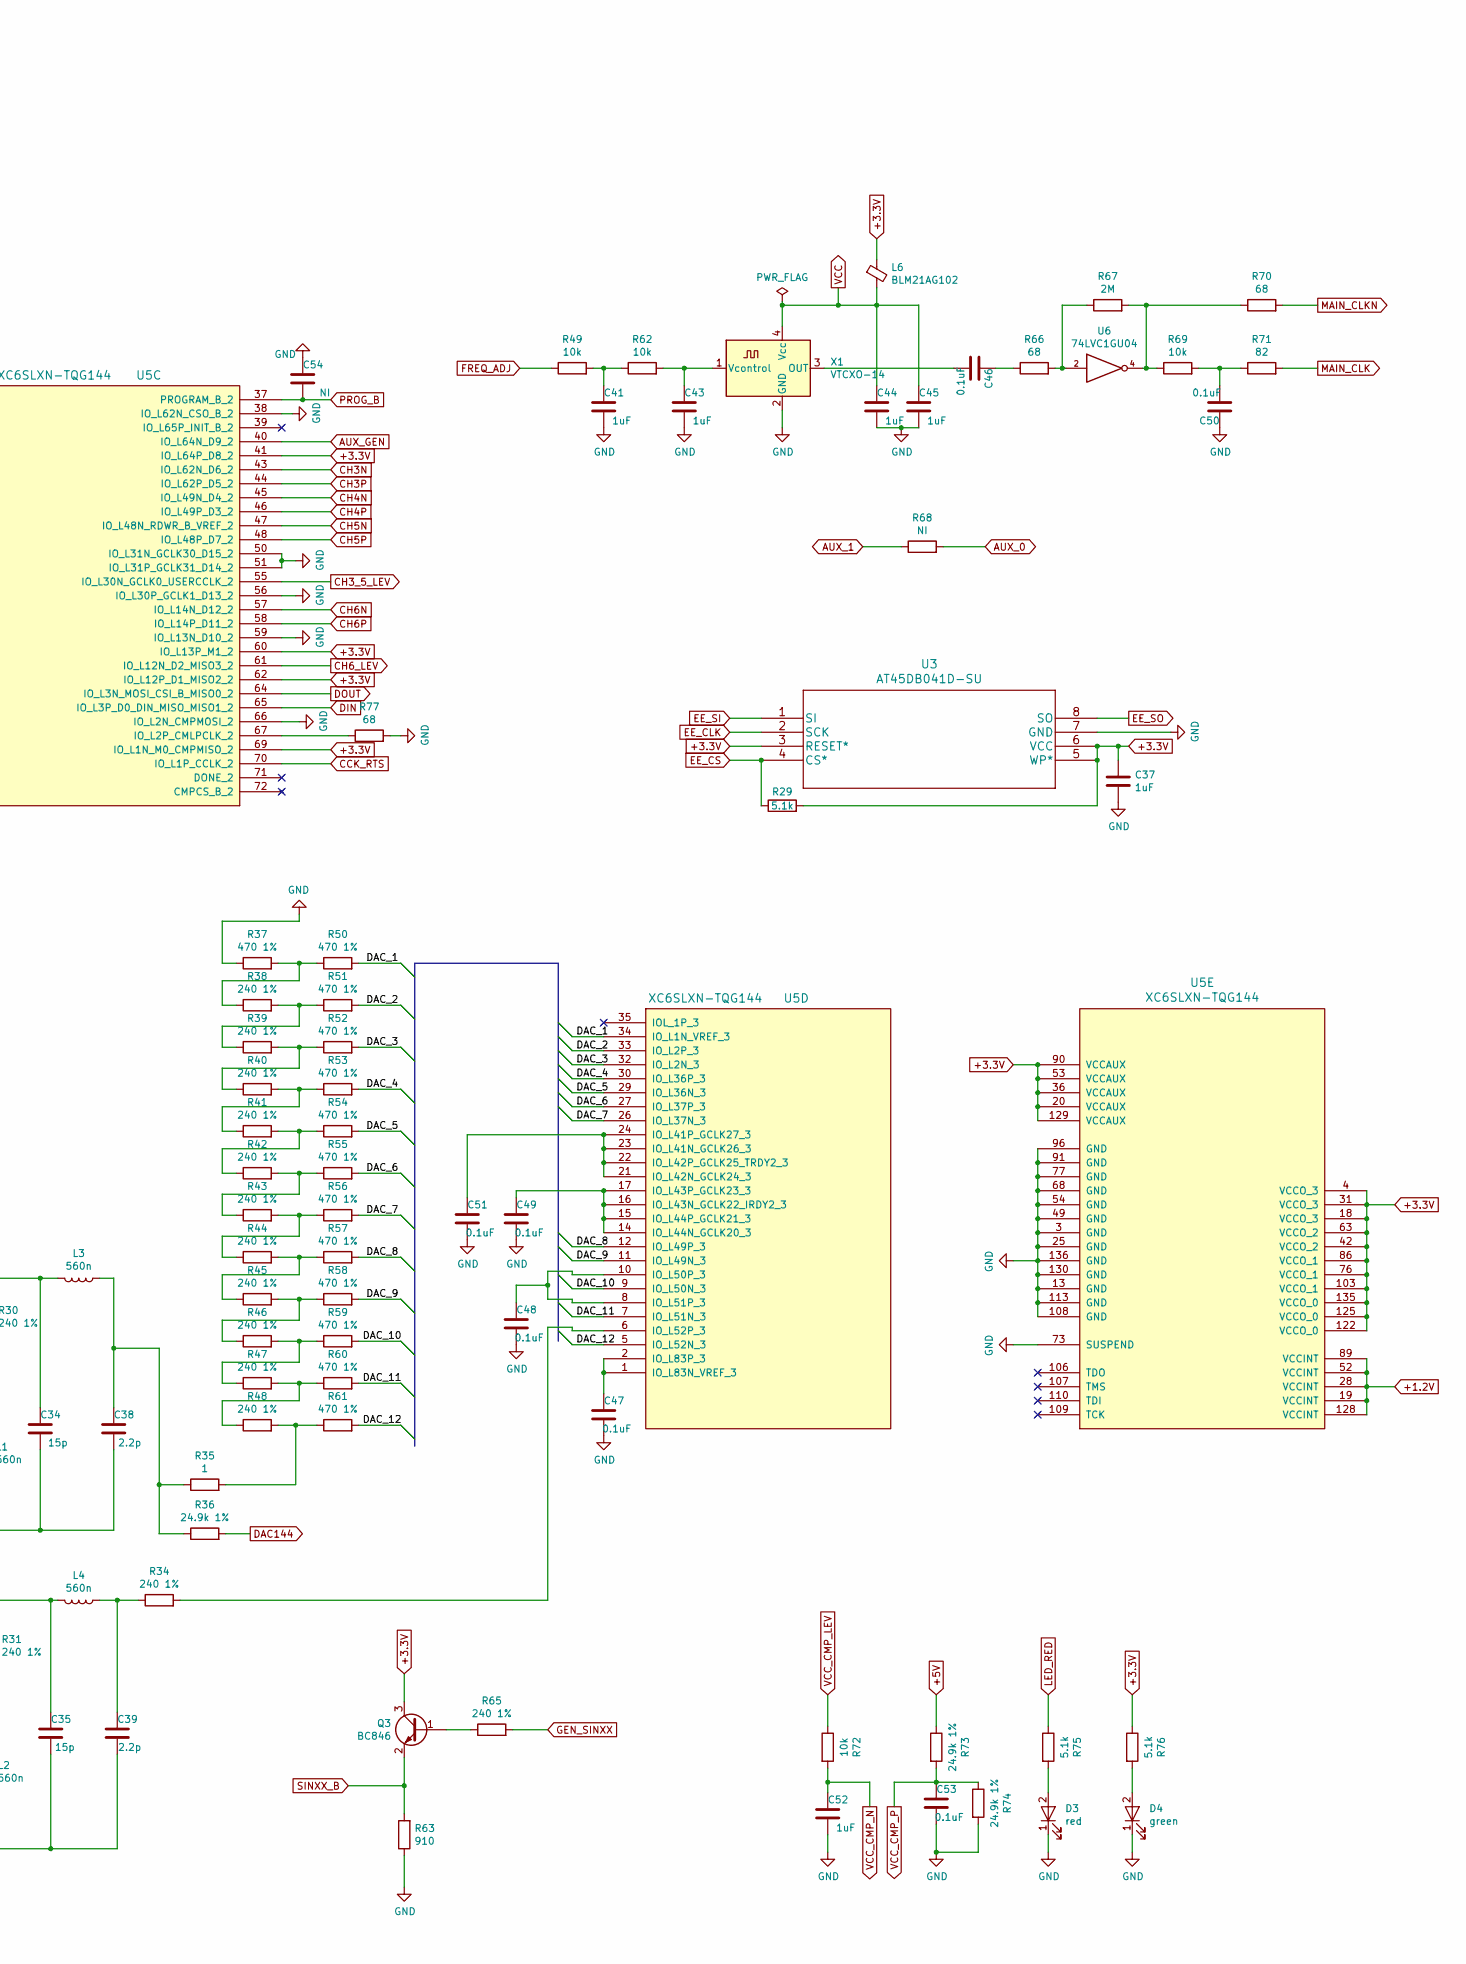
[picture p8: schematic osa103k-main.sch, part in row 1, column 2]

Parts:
C1, C6, C10, C13: 10uF; C_0805
C2: 22uF; C_1206
C3, C15, C34, C35: 15p; C_0603
C4, C14: 470p; C_0805
C5, C38, C39: 2.2p; C_0603
C7, C8, C19, C20, C21, C22, C23, C37, C41, C43, C44, C45, C52: 1uF; C_0603
C9, C16, C17, C54: NI; C_0603
C11, C12, C46, C47, C48, C49, C50, C51, C53: 0.1uF; C_0603
C18: 3..10p; C_Trimmer_Murata_TZC3
C27, C28: 6.2p; C_0603
D1, D2: BAV99; SOT-23
D3: red; LED_0805
D4: green; LED_0805
J1, J2: Conn_Coaxial; Molex_SMA_Jack_Edge_Mount
J3, J6: Conn_01x03; Pin_Header_Straight_1x03_Pitch2.54mm
L1, L2, L3, L4: 560n; Neosid_Inductor_SM-NE29_SMD1008
L6: BLM21AG102; R_0805
Q1, Q2, Q3: BC846; SOT-23
R1, R6: 49.9 1%; R_1206
R2, R3, R35: 1; R_0603
R4: 2k 1%; R_0603
R5, R10: 10; R_0603
R7, R8, R15, R16, R71: 82; R_0603
R9, R12, R27, R63: 910; R_0603
R11, R21: 270; R_0603
R13, R49, R62, R69, R72: 10k; R_0603
R14: 390; R_0603
R17, R20: 20k; R_0603
R19, R68: NI; R_0603
R22, R23: 200; R_0603
R25, R37, R50, R51, R52, R53, R54, R55, R56, R57, R58, R59, R60, R61: 470 1%; R_0603
R26, R30, R31, R34, R38, R39, R40, R41, R42, R43, R44, R45, R46, R47, R48, R65: 240 1%; R_0603
R28, R67: 2M; R_0603
R29, R75, R76: 5.1k; R_0603
R36, R73, R74: 24.9k 1%; R_0603
R66, R70, R77: 68; R_0603
RN1, RN2, RN3, RN4: 150; R_Array_Convex_4x0603
RV18: 20k; Potentiometer_Trimmer_Vishay_TS53YJ
RV24: 1k; Potentiometer_Trimmer_Vishay_TS53YJ
U1: AD8009ARZ; SOIC-8_3.9x4.9mm_Pitch1.27mm
U2: AD9288BST-40; LQFP-48_7x7mm_Pitch0.5mm
U3: AT45DB041D-SU; SOIC-8_3.9x4.9mm_Pitch1.27mm
U5: XC6SLXN-TQG144; TQFP-144_20x20mm_Pitch0.5mm
U6: 74LVC1GU04; SOT-23-5
X1: VTCXO-14; Crystal_SMD_SeikoEpson_TSX3225-4pin_3.2x2.5mm

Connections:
+1.2V: U5.19 (VCCINT), U5.28 (VCCINT), U5.52 (VCCINT), U5.89 (VCCINT), U5.128 (VCCINT); also elsewhere on the board
+3.3V: C37.2, L6.1, Q3.3 (C), R29.2, R76.1, RV18.2, U3.3 (RESET*), U3.5 (WP*), U3.6 (VCC), U5.4 (VCCO_3), U5.18 (VCCO_3), U5.20 (VCCAUX), U5.31 (VCCO_3), U5.36 (VCCAUX), U5.41 (IO_L64P_D8_2), U5.42 (VCCO_2), U5.53 (VCCAUX), U5.60 (IO_L13P_M1_2), U5.62 (IO_L12P_D1_MISO2_2), U5.63 (VCCO_2), U5.69 (IO_L1N_M0_CMPMISO_2), U5.76 (VCCO_1), U5.86 (VCCO_1), U5.90 (VCCAUX), U5.103 (VCCO_1), U5.122 (VCCO_0), U5.125 (VCCO_0), U5.129 (VCCAUX), U5.135 (VCCO_0); also elsewhere on the board
+5V: R73.1; also elsewhere on the board
+5V_GEN: C10.1, C11.1, U1.7 (VS+); also elsewhere on the board
-5V_GEN: C12.1, C13.1, U1.4 (VS-); also elsewhere on the board
/osa103k Main/ADC0_0: RN3.5 (R4.2), U5.105 (IO_L1P_1)
/osa103k Main/ADC0_1: RN3.6 (R3.2), U5.104 (IO_L1N_VREF_1)
/osa103k Main/ADC0_2: RN3.7 (R2.2), U5.102 (IO_L32P_1)
/osa103k Main/ADC0_3: RN3.8 (R1.2), U5.101 (IO_L32N_1)
/osa103k Main/ADC0_4: RN1.5 (R4.2), U5.100 (IO_L33P_1)
/osa103k Main/ADC0_5: RN1.6 (R3.2), U5.99 (IO_L33N_1)
/osa103k Main/ADC0_6: RN1.7 (R2.2), U5.98 (IO_L34P_1)
/osa103k Main/ADC0_7: RN1.8 (R1.2), U5.97 (IO_L34N_1)
/osa103k Main/ADC1_0: RN4.8 (R1.2), U5.111 (IO_L66N_SCP0_0)
/osa103k Main/ADC1_1: RN4.7 (R2.2), U5.112 (IO_L66P_SCP1_0)
/osa103k Main/ADC1_2: RN4.6 (R3.2), U5.114 (IO_L65N_SCP2_0)
/osa103k Main/ADC1_3: RN4.5 (R4.2), U5.115 (IO_L65P_SCP3_0)
/osa103k Main/ADC1_4: RN2.8 (R1.2), U5.116 (IO_L64N_SCP4_0)
/osa103k Main/ADC1_5: RN2.7 (R2.2), U5.117 (IO_L64P_SCP5_0)
/osa103k Main/ADC1_6: RN2.6 (R3.2), U5.118 (IO_L63N_SCP6_0)
/osa103k Main/ADC1_7: RN2.5 (R4.2), U5.119 (IO_L63P_SCP7_0)
/osa103k Main/DAC_1: R50.2, U5.34 (IO_L1N_VREF_3)
/osa103k Main/DAC_2: R51.2, U5.33 (IO_L2P_3)
/osa103k Main/DAC_3: R52.2, U5.32 (IO_L2N_3)
/osa103k Main/DAC_4: R53.2, U5.30 (IO_L36P_3)
/osa103k Main/DAC_5: R54.2, U5.29 (IO_L36N_3)
/osa103k Main/DAC_6: R55.2, U5.27 (IO_L37P_3)
/osa103k Main/DAC_7: R56.2, U5.26 (IO_L37N_3)
/osa103k Main/DAC_8: R57.2, U5.12 (IO_L49P_3)
/osa103k Main/DAC_9: R58.2, U5.11 (IO_L49N_3)
/osa103k Main/DAC_10: R59.2, U5.9 (IO_L50N_3)
/osa103k Main/DAC_11: R60.2, U5.7 (IO_L51N_3)
/osa103k Main/DAC_12: R61.2, U5.5 (IO_L52N_3)
ADC0_ENC: R15.2, U5.95 (IO_L40P_GCLK11_1)
ADC1_ENC: R16.2, U5.121 (IO_L62P_0)
AUX_0: R68.2, U5.88 (IO_L42P_GCLK7_1)
AUX_1: R68.1, U5.87 (IO_L42N_GCLK6_TRDY1_1)
AUX_GEN: U5.40 (IO_L64N_D9_2); also elsewhere on the board
CCK_RTS: U5.70 (IO_L1P_CCLK_2); also elsewhere on the board
CH1_DITH: R11.1, U5.124 (IO_L37P_GCLK13_0)
CH3N: U5.43 (IO_L62N_D6_2); also elsewhere on the board
CH3P: U5.44 (IO_L62P_D5_2); also elsewhere on the board
CH3_5_LEV: U5.55 (IO_L30N_GCLK0_USERCCLK_2); also elsewhere on the board
CH4N: U5.45 (IO_L49N_D4_2); also elsewhere on the board
CH4P: U5.46 (IO_L49P_D3_2); also elsewhere on the board
CH5N: U5.47 (IO_L48N_RDWR_B_VREF_2); also elsewhere on the board
CH5P: U5.48 (IO_L48P_D7_2); also elsewhere on the board
CH6N: U5.57 (IO_L14N_D12_2); also elsewhere on the board
CH6P: U5.58 (IO_L14P_D11_2); also elsewhere on the board
CH6_LEV: U5.61 (IO_L12N_D2_MISO3_2); also elsewhere on the board
DAC144: R36.2, U5.144 (IO_L1P_HSWAPEN_0)
DIN: U5.65 (IO_L3P_D0_DIN_MISO_MISO1_2); also elsewhere on the board
DOUT: U5.64 (IO_L3N_MOSI_CSI_B_MISO0_2); also elsewhere on the board
EE_CLK: U3.2 (SCK), U5.131 (IO_L35N_GCLK16_0)
EE_CS: R29.1, U3.4 (CS*), U5.132 (IO_L35P_GCLK17_0)
EE_SI: U3.1 (SI), U5.127 (IO_L36P_GCLK15_0)
EE_SO: U3.8 (SO), U5.126 (IO_L36N_GCLK14_0)
FREQ_ADJ: R49.1, U5.81 (IO_L46P_1)
GEN_SINXX: R65.2, U5.143 (IO_L1N_VREF_0)
GND: C3.1, C4.1, C6.1, C8.2, C10.2, C11.2, C12.2, C13.2, C14.2, C16.2, C17.1, C18.2, C19.2, C20.2, C27.1, C28.2, C34.2, C35.2, C37.1, C38.2, C39.2, C41.2, C43.2, C44.2, C45.2, C47.2, C48.2, C49.2, C50.1, C51.2, C52.2, C53.2, C54.1, D1.1 (A), D3.1 (K), D4.1 (K), J1.2 (Ext), J2.2 (Ext), J3.1, J6.1, L1.2, L2.1, Q1.2 (E), Q2.2 (E), R7.1, R14.1, R21.1, R37.1, R63.1, R74.2, R77.2, U2.1 (GND), U2.4 (DFS), U2.9 (S2), U2.12 (GND), U2.16 (GND), U2.27 (GND), U2.29 (GND), U2.32 (GND), U2.34 (GND), U2.45 (GND), U3.7 (GND), U5.3 (GND), U5.13 (GND), U5.25 (GND), U5.38 (IO_L62N_CSO_B_2), U5.49 (GND), U5.50 (IO_L31N_GCLK30_D15_2), U5.51 (IO_L31P_GCLK31_D14_2), U5.54 (GND), U5.56 (IO_L30P_GCLK1_D13_2), U5.59 (IO_L13N_D10_2), U5.66 (IO_L2N_CMPMOSI_2), U5.68 (GND), U5.73 (SUSPEND), U5.77 (GND), U5.80 (IO_L46N_1), U5.82 (IO_L45N_1), U5.83 (IO_L45P_1), U5.91 (GND), U5.93 (IO_L41P_GCLK9_IRDY1_1), U5.96 (GND), U5.108 (GND), U5.113 (GND), U5.120 (IO_L62N_VREF_0), U5.123 (IO_L37N_GCLK12_0), U5.130 (GND), U5.136 (GND), U5.142 (IO_L2P_0), U6.3 (GND), X1.2 (GND); also elsewhere on the board
LED_RED: R75.1, U5.74 (IO_L74N_DOUT_BUSY_1)
MAIN_CLK: R71.2, U5.85 (IO_L43P_GCLK5_1)
MAIN_CLKN: R70.2, U5.84 (IO_L43N_GCLK4_1)
unnamed: C1.1, C2.1, R5.1
unnamed: C1.2, C2.2, J1.1 (In), R1.1
unnamed: C3.2, C4.2, R7.2, R8.1, R9.2
unnamed: C5.1, J2.1 (In), R6.2
unnamed: C5.2, J6.3, R4.1, R6.1, R12.2, U1.6 (OUT)
unnamed: C6.2, D2.1 (A), D2.2 (K)
unnamed: C7.1, R8.2
unnamed: C7.2, U2.2 (AINA), U2.11 (AINB)
unnamed: C8.1, U2.5 (REFINA), U2.6 (REFOUT), U2.7 (REFINB)
unnamed: C9.1, R10.2, U2.3 (AINA*), U2.10 (AINB*)
unnamed: C9.2, D1.3 (K), R5.2, R10.1
unnamed: C14.1, R17.1
unnamed: C15.1, C18.1
unnamed: C15.2, R15.1, U2.47 (ENCA)
unnamed: C16.1, R19.1
unnamed: C17.2, R16.1, U2.14 (ENCB)
unnamed: C19.1, Q1.1 (B), R26.1
unnamed: C20.1, Q2.1 (B), R27.1
unnamed: C21.1, C22.1, C27.2, L1.1, R28.2, R30.1
unnamed: C21.2, C22.2, Q1.3 (C), R28.1
unnamed: C23.1, C28.1, L2.2, R31.1
unnamed: C23.2, Q2.3 (C)
unnamed: C34.1, L3.2, R22.2, R30.2, RV24.2, RV24.3
unnamed: C35.1, L4.2, R23.2, R25.1, R31.2
unnamed: C38.1, L3.1, R35.1, R36.1
unnamed: C39.1, L4.1, R34.1
unnamed: C41.1, R49.2, R62.1
unnamed: C43.1, R62.2, X1.1 (Vcontrol)
unnamed: C46.1, R66.1
unnamed: C46.2, X1.3 (OUT)
unnamed: C47.1, U5.1 (IO_L83N_VREF_3), U5.2 (IO_L83P_3)
unnamed: C48.1, U5.8 (IO_L51P_3), U5.10 (IO_L50P_3)
unnamed: C49.1, U5.14 (IO_L44N_GCLK20_3), U5.15 (IO_L44P_GCLK21_3), U5.16 (IO_L43N_GCLK22_IRDY2_3), U5.17 (IO_L43P_GCLK23_3)
unnamed: C50.2, R69.2, R71.1
unnamed: C51.1, U5.21 (IO_L42N_GCLK24_3), U5.22 (IO_L42P_GCLK25_TRDY2_3), U5.23 (IO_L41N_GCLK26_3), U5.24 (IO_L41P_GCLK27_3)
unnamed: D2.3 (K), R9.1, R11.2
unnamed: D3.2 (A), R75.2
unnamed: D4.2 (A), R76.2
unnamed: J3.2, R2.2, R3.2
unnamed: J3.3, J6.2, R4.2
unnamed: Q3.1 (B), R65.1
unnamed: R1.2, R2.1, R3.1
unnamed: R12.1, R13.1, R14.2, R17.2, R19.2, R23.1, U1.2 (IN-)
unnamed: R13.2, RV18.1
unnamed: R20.1, R21.2, R22.1, U1.3 (IN+)
unnamed: R20.2, RV18.3
unnamed: R25.2, RV24.1
unnamed: R34.2, U5.6 (IO_L52P_3)
unnamed: R35.2, R48.2, R61.1
unnamed: R37.2, R38.1, R50.1
unnamed: R38.2, R39.1, R51.1
unnamed: R39.2, R40.1, R52.1
unnamed: R40.2, R41.1, R53.1
unnamed: R41.2, R42.1, R54.1
unnamed: R42.2, R43.1, R55.1
unnamed: R43.2, R44.1, R56.1
unnamed: R44.2, R45.1, R57.1
unnamed: R45.2, R46.1, R58.1
unnamed: R46.2, R47.1, R59.1
unnamed: R47.2, R48.1, R60.1
unnamed: R66.2, R67.1, U6.2
unnamed: R67.2, R69.1, R70.1, U6.4
unnamed: R77.1, U5.67 (IO_L2P_CMLPCLK_2)
unnamed: RN1.1 (R1.1), U2.44 (D7A_MSB)
unnamed: RN1.2 (R2.1), U2.43 (D6A)
unnamed: RN1.3 (R3.1), U2.42 (D5A)
unnamed: RN1.4 (R4.1), U2.41 (D4A)
unnamed: RN2.1 (R1.1), U2.20 (D4B)
unnamed: RN2.2 (R2.1), U2.19 (D5B)
unnamed: RN2.3 (R3.1), U2.18 (D6B)
unnamed: RN2.4 (R4.1), U2.17 (D7B_MSB)
unnamed: RN3.1 (R1.1), U2.40 (D3A)
unnamed: RN3.2 (R2.1), U2.39 (D2A)
unnamed: RN3.3 (R3.1), U2.38 (D1A)
unnamed: RN3.4 (R4.1), U2.37 (D0A)
unnamed: RN4.1 (R1.1), U2.24 (D0B)
unnamed: RN4.2 (R2.1), U2.23 (D1B)
unnamed: RN4.3 (R3.1), U2.22 (D2B)
unnamed: RN4.4 (R4.1), U2.21 (D3B)
PROG_B: C54.2, U5.37 (PROGRAM_B_2); also elsewhere on the board
SINXX_B: Q3.2 (E), R26.2, R27.2, R63.2
VCC: C44.1, C45.1, L6.2, U6.5 (VCC), X1.4 (Vcc)
VCC_CMP_LEV: R72.1, U5.75 (IO_L74P_AWAKE_1)
VCC_CMP_N: C52.1, R72.2, U5.78 (IO_L47N_1)
VCC_CMP_P: C53.1, R73.2, R74.1, U5.79 (IO_L47P_1)
VD+3.3: D1.2 (K), U2.8 (S1), U2.13 (VD), U2.30 (VD), U2.31 (VD), U2.48 (VD); also elsewhere on the board
VDD+3.3: U2.15 (VDD), U2.28 (VDD), U2.33 (VDD), U2.46 (VDD); also elsewhere on the board

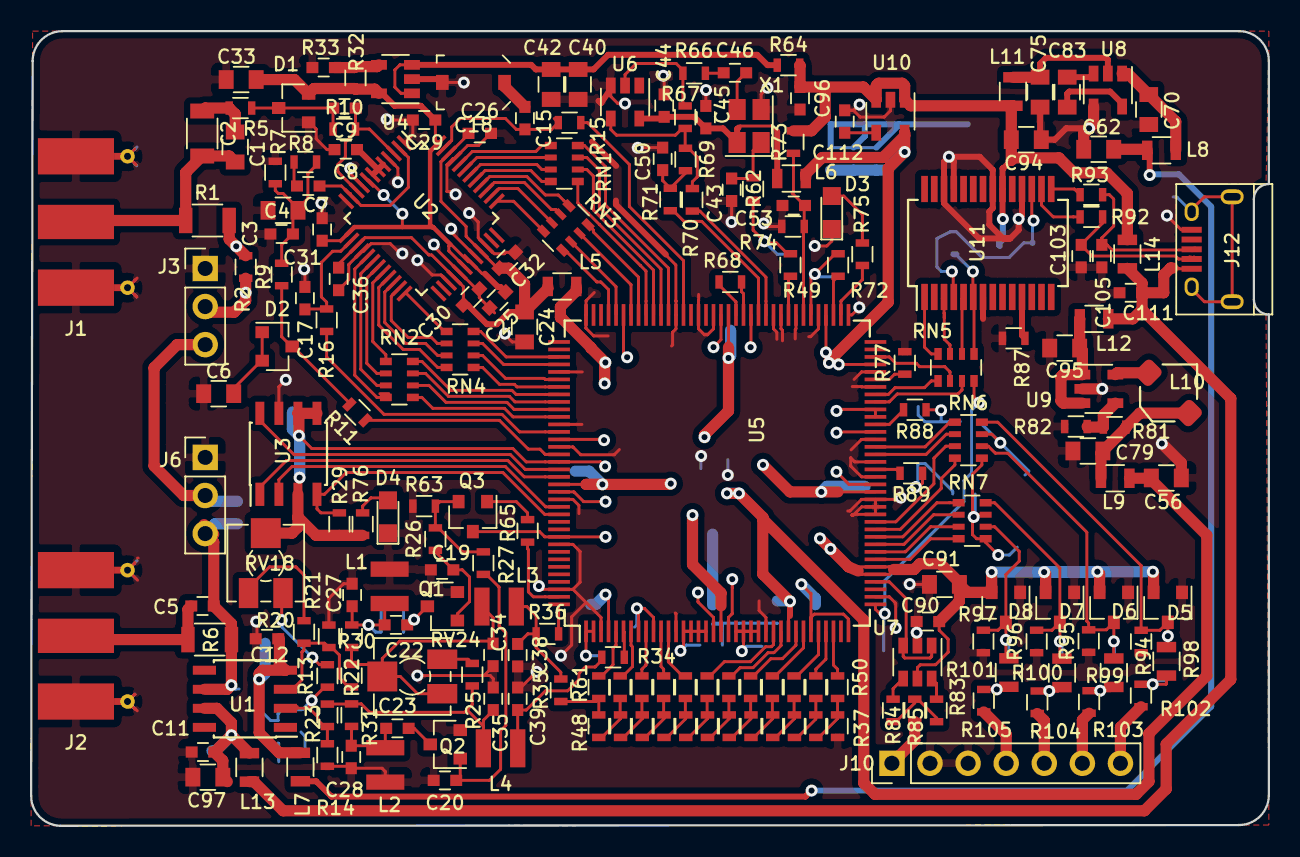
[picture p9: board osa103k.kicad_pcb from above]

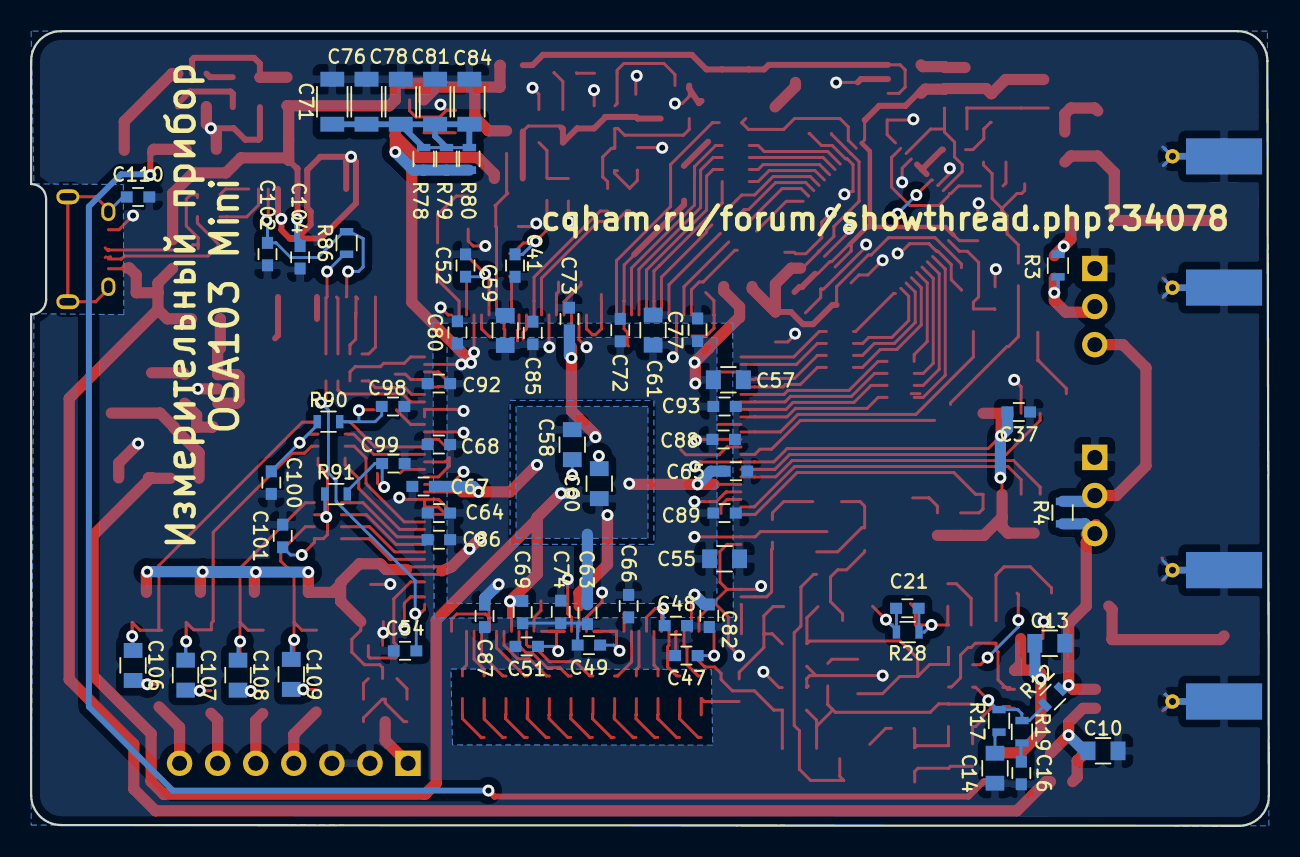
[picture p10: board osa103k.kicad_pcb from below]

Board: 2 copper layers, 82.5 x 53.0 mm, 267 parts (67 on the bottom side), 195 nets.

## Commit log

2023-03-20 Publish KiCad project and gerber files
    [LCSC_Bom-osa.xlsx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]
2023-03-20 create top level directory
    [LCSC_Bom-osa.xlsx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]
